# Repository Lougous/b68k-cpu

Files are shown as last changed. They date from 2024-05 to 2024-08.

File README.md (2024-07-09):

# Overview

This is a single board computer based on Motorola 68000. It features:
* 512kiB to 8MiB DRAM (SIMM 30 pins x2)
* basic memory protection / paging
* 8bits expansion bus with 4 slots
* PS/2 keyboard and mouse support
* serial link (TTL)
* boot with serial bootstrap or user flash

Some pictures [here](/doc).

The block diagram below depicts the board architecture:
board architecture

## Board glue logic

Most board glue logic is implemented with an Altera EPM7128S CPLD. This part is obsolete but modern replacement exists with ~~Actel~~ ~~Microsemi~~ Microchip ATF1508AS (never tested though). The CPLD implements:
* DRAM address multiplexing
* DRAM refresh
* basic memory management: base address translation and inbound check with power of two alignment constraints
* 8-bits expansion bus access, for 8-bits wide or 16-bits wide memory cycle from the 68000
* first stage boot procedure, by copying during reset the 512 first bytes from the flash memory (see MFP chip description below) at address 000000h in DRAM. 

Expansion bus also uses a few discrete logic (74245 buffers and 74138 address decoder).

An additional 74148 encodes interrupt sources to CPU IPL0/1/2.

### memory management

The CPLD provides very basic memory management capabilities, for user mode accesses only (FC2 set to 0). It relies on two value set with four registers. These registers are write only, 16-bits, but only the upper bit 15:8 are used.

| register | address | description |
|:---:|:---:|:---|
| MMU_BASE_LO | FE0000h | base address bits 19:12 |
| MMU_BASE_HI | FE0002h | base address bits 22:20 |
| MMU_MASK_LO | FE0004h | address mask bits 19:12 |
| MMU_MASK_HI | FE0006h | address mask bits 21:20 |

Any user address is and'ed with MMU_MASK then or'ed with MMU_BASE. It results in a memory area allocated to a user program with a power of two size, with a base address aligned to its own size. Any user access that targets an address above the allocated size ends with a bus error.

### interrupt management

The autovectored interrupt scheme is used (VPA# assertion). To save pins on the CPLD the FC0 and FC1 are not available to identify an interrupt acknowledge cycle, so any read cycle at FFFFFFh with FC2 set to 1 is considered as such.

### 8-bits expansion bus

This bus provides access to 5 peripherals:
* 4 available through dedicated connectors (2x10 female pin headers)
* 1 embeded to the board: the MFP

It provides for each peripheral up to 128kiB aperture into CPU memory space.

The table below lists the signals on this bus as seen for each slot.

| signal  | type | shared  | description |
|:---:|:---:|:---:|:---:|
| RST# | input | yes | system reset |
| CE# | input | no | access enable |
| ACK# | open drain output | yes | access acknowledge |
| WE# | input | yes | write enable |
| ALE# | input | yes | address latch enable |
| IRQ# | open drain output | option  | interrupt request |
| A0 | input | yes | address bit 0 |
| AD[7:0] | bidir | yes | address / data |

#### single access cycles

This is how translates a byte access from the 68000 (UDS# or LDS# alone)

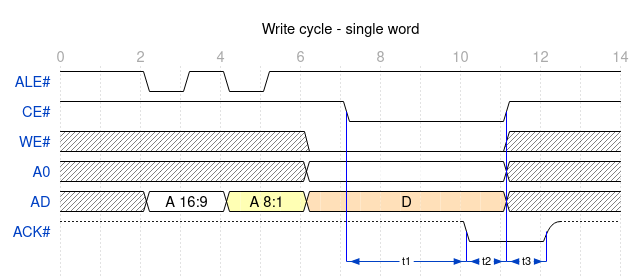
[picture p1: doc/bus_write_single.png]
Write cycle - single word

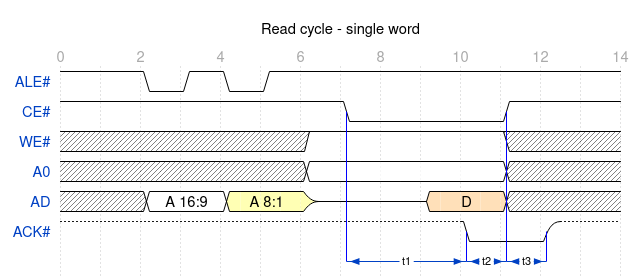
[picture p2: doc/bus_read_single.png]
Read cycle - single word


note: peripherals like the MFP ignore the address bits 16:1 and can ignore the ALE# signal.

#### multiple access cycles

This is how translates a 16-bits access from the 68000 (UDS# and LDS#)

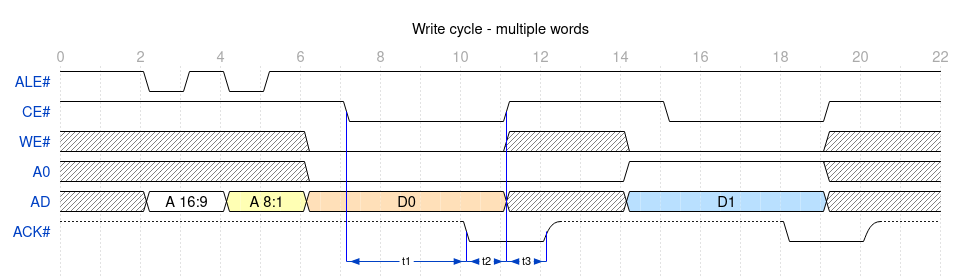
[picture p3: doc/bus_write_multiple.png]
Write cycle - multiple words


### Bootstrap loading

Right after a reset, the CPLD starts by transfering 512 bytes of data from the MFP FLASH_DATA register into the first bytes of DRAM. Then the very first 68000 memory access (at 0000000h) is performed.

Because any software is to be much bigger than just 512-bytes, this chunk of code must itself include assembly instructions to copy the rest of the code - still accessing FLASH_DATA register.

The MFP contains two software images for the 68000:
* a serial bootstrap, loading from the serial interface the binary to jump in, that is enables by pressing 's' key on a keyboard plugged into the PS/2 port
* or an embedded binary to jump in.

To change the embedded binary, the MFP firmware must be recompiled and programmed (the 68000 binary is a constant data table within the microcontroller firmware).

## MFP (multifunction peripheral)

This is a software defined chip base on a PIC18F27K42 microcontroller. It provides:
* embedded flash with 2 software images for the 68000, selection by detecting pressed key at reset. 
* IOs/timer with dedicated low-priority interrupt: two PS/2 port, one serial link, 1 kHz RTC timer
* 250 Hz system timer with dedicated highest-priority interrupt
* hard/soft reset
* debug register (POST or so)

The MFP has only two memory locations accessible through the expansion bus: one to set the actual register to access, the other to read or write data from/to the register.

| register | address | description |
|:---:|:---:|:---|
| MFP_DATA | F00000h | MFP register data |
| MFP_ADDRESS | F00001h | MFP register index |

### Register set

| register | index | description |
|:---:|:---:|:---|
| FLASH_DATA  | 0 | boot flash data access. flash data pointer auto increments |
| TICKS | 3 | 4-us ticks counter, 0-249 |
| UART_STS | 4 | UART status<br>bit 7: TX ready<br>bit 1: RX FIFO overflow<br>bit 0: RX FIFO underflow |
| UART_DATA | 5 | UART data in/out |
| POST | 7 | POST code (debug) |
| PS2P0_STS | 8 | PS/2 port 0 status<br>bit 0: data available |
| PS2P0_DATA  | 9 | PS/2 port 0 data |
| PS2P1_STS | 10 | PS/2 port 1 status<br>bit 0: data available |
| PS2P1_DATA  | 11 | PS/2 port 1 data |
| SYSCFG | 12 | system tick configuration<br>bit 0: enable timer interrupt<br>bit 5: set by bootstap loader to prevent flash to RAM boot transfer<br>bit 6: enable self immediate interrupt<br>bit 7: soft reset |
| SYSSTS | 13 |  system tick status<br>bit 0: timer interrupt pending<br>bit 6: self immediate interrupt pending |
| IRQCFG | 14 | interrupt controller configuration<br>bit 0: enable RTC interrupt<br>bit 1: enable PS/2 keyboard interrupt<br>bit 2: enable PS/2 mouse interrupt<br>bit 3: enable UART RX interrupt |
| IRQSTS | 15 | interrupt controller status<br>bit 0: RTC interrupt pending<br>bit 1: PS/2 keyboard interrupt pending<br>bit 2: PS/2 mouse interrupt pending<br>bit 3: UART RX interrupt pending |

# Memory mapping

| memory range | access | size | memory area
|:---:|:---:|:---:|:-----
| 000000h - 7FFFFFh | U/S | 8MiB | DRAM. memory address translation/mask/check for user mode only |
| 800000h - EFFFFFh | S	 | 7MiB | DO NOT USE. mirrors F00000h - FFFFFFh |
| F00000h - F1FFFFh | S | 128kiB | MFP registers. address bits 16:1 are ignored |
| F20000h - F3FFFFh | S | 128kiB | expansion bus connector J9 |
| F40000h - F5FFFFh | S | 128kiB | expansion bus connector J11 |
| F60000h - F7FFFFh | S | 128kiB | DO NOT USE. reserved for expansion bus hardware implementation |
| F80000h - F9FFFFh | U*/S | 128kiB | expansion bus connector J10. *: user access to be removed |
| FA0000h - FBFFFFh | S | 128kiB | DO NOT USE. unmapped, might be used for another peripheral slot |
| FC0000h - FDFFFFh | S | 128kiB | expansion bus connector J8 |
| FE0000h - FFFFFFh | S | 128kiB | restricted to PMMU register configuration |

# BOM

This table below is no spec, it just shows the parts that equip the board on my desk.

| Reference  | Part |
|:---:|:---:|
| RN1 | not populated |
| U1 | MC68HC000FN20 |
| U2 | 74F138 |
| U3, U6, U7 | 74F245 |
| U4 | EPM7128SLC84-10 |
| U5 | PIC18F27K42SP |
| U8 | 74HC148 |
| X2 | 12-MHz |

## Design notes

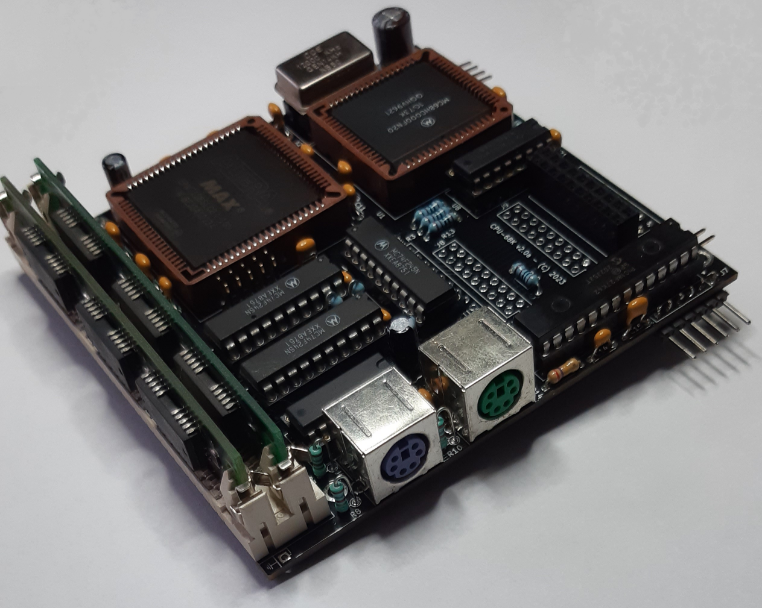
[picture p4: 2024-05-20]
doc/b68k-cpu.png

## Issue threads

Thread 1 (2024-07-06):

boot sector corruption at startup

Lougous, 2024-07-06:
The very first byte copied from MFP to DRAM by the boot DMA is sometimes corrupted.
First byte copied is at address 000001h => part of reset stack address, that is not used (set by dedicated instruction in reset handler)

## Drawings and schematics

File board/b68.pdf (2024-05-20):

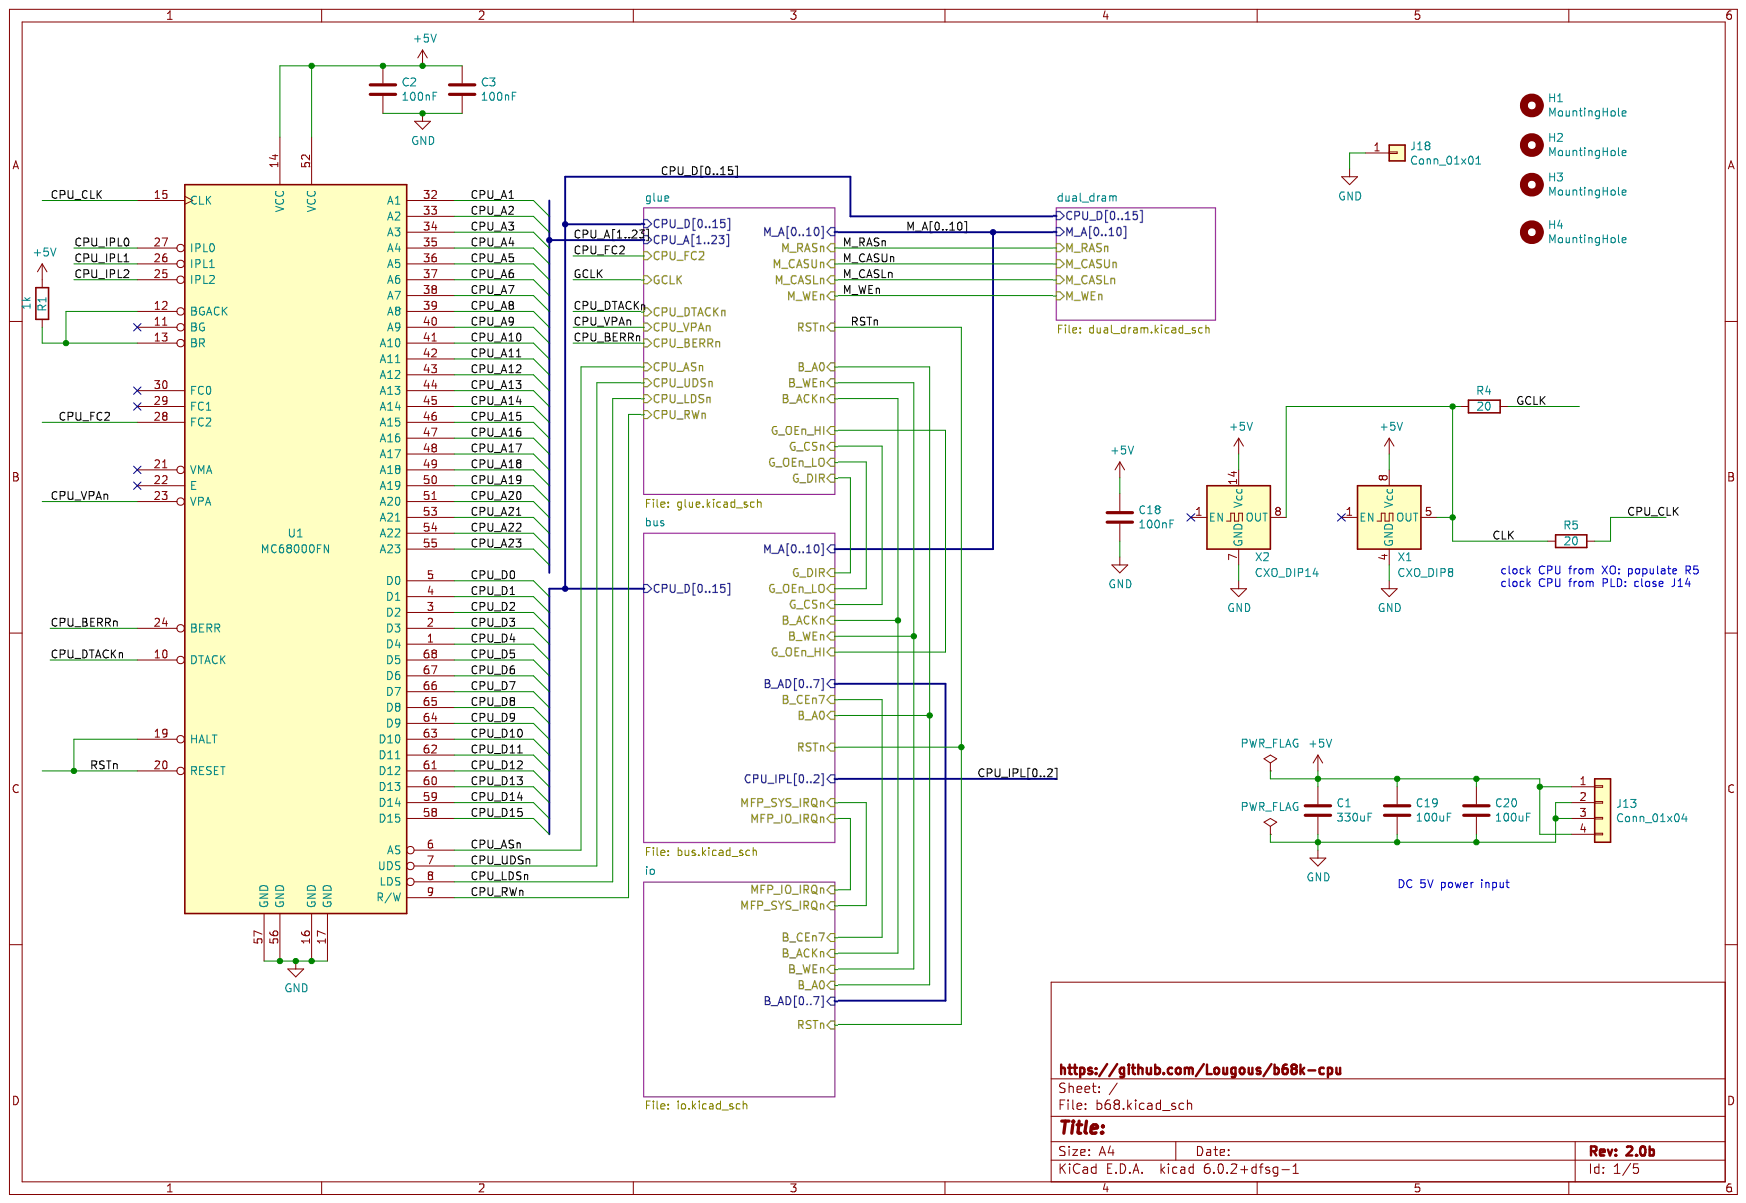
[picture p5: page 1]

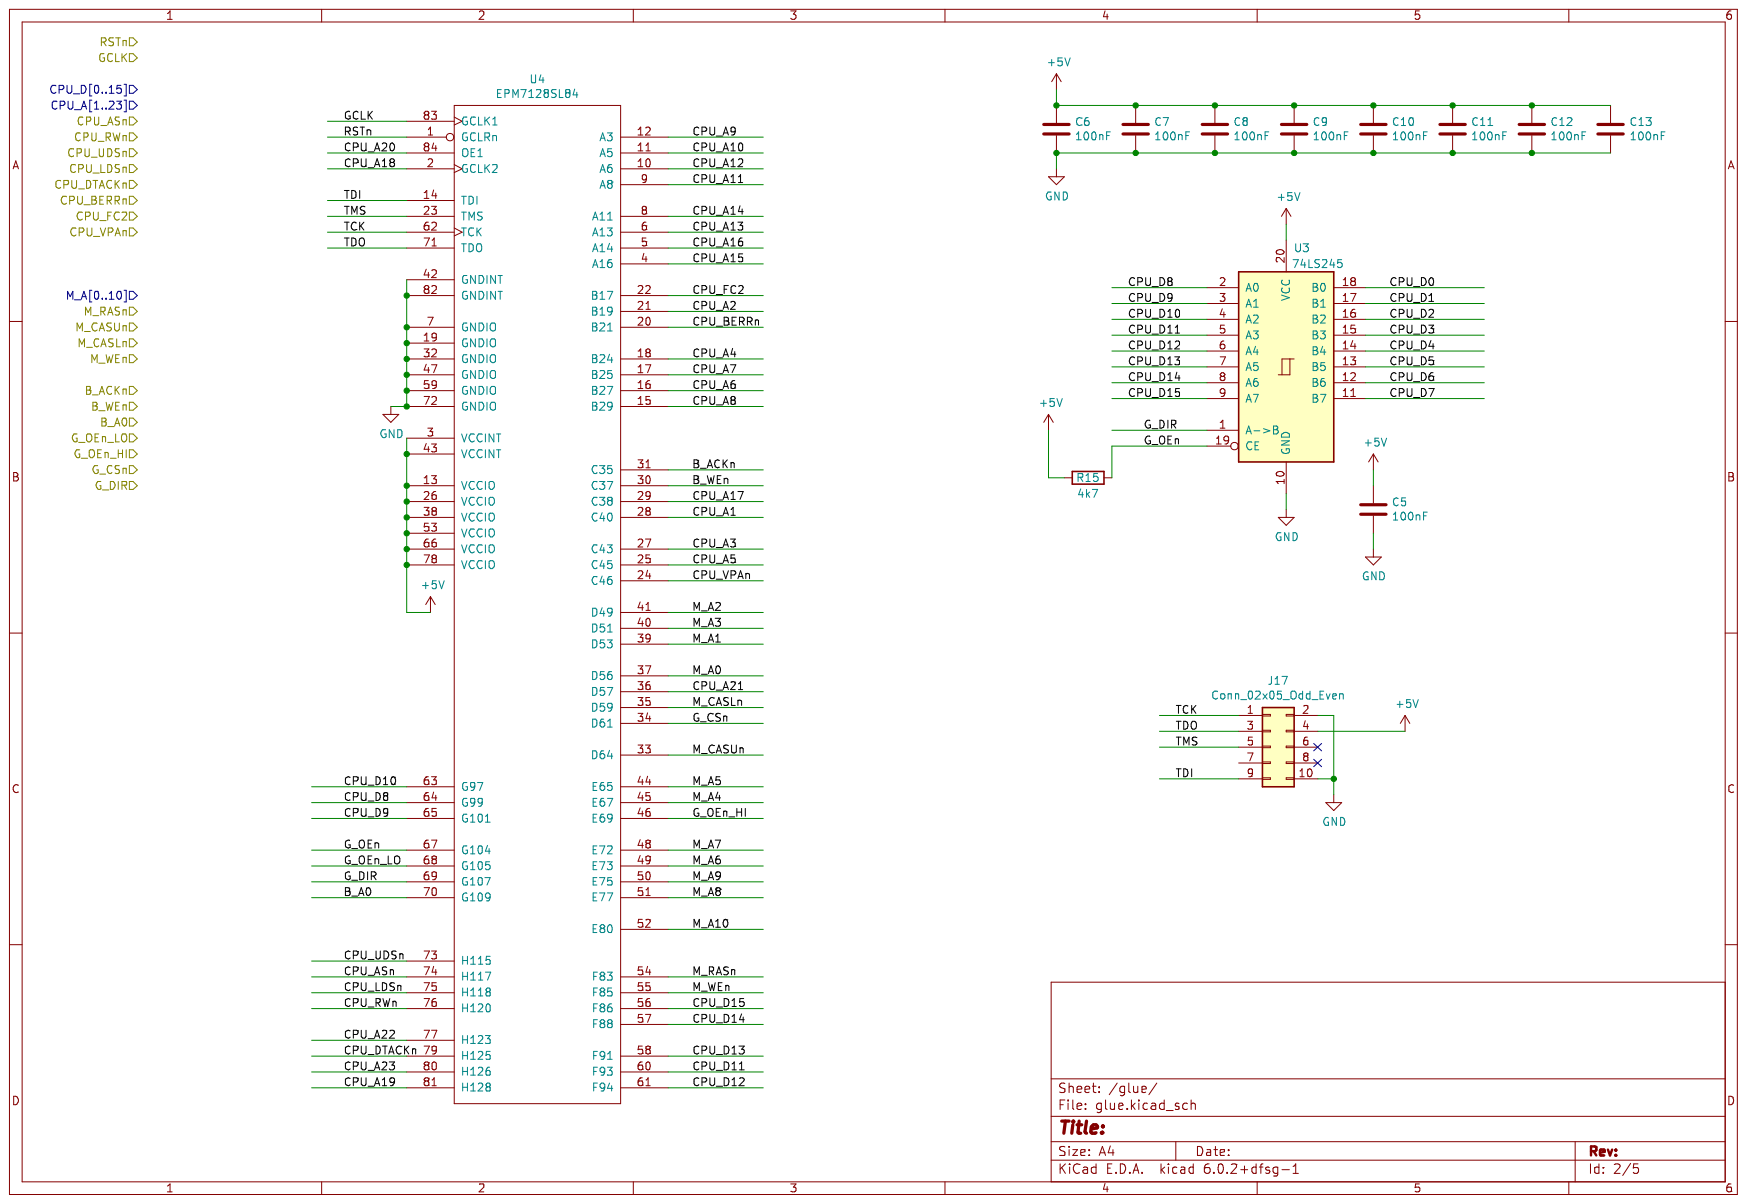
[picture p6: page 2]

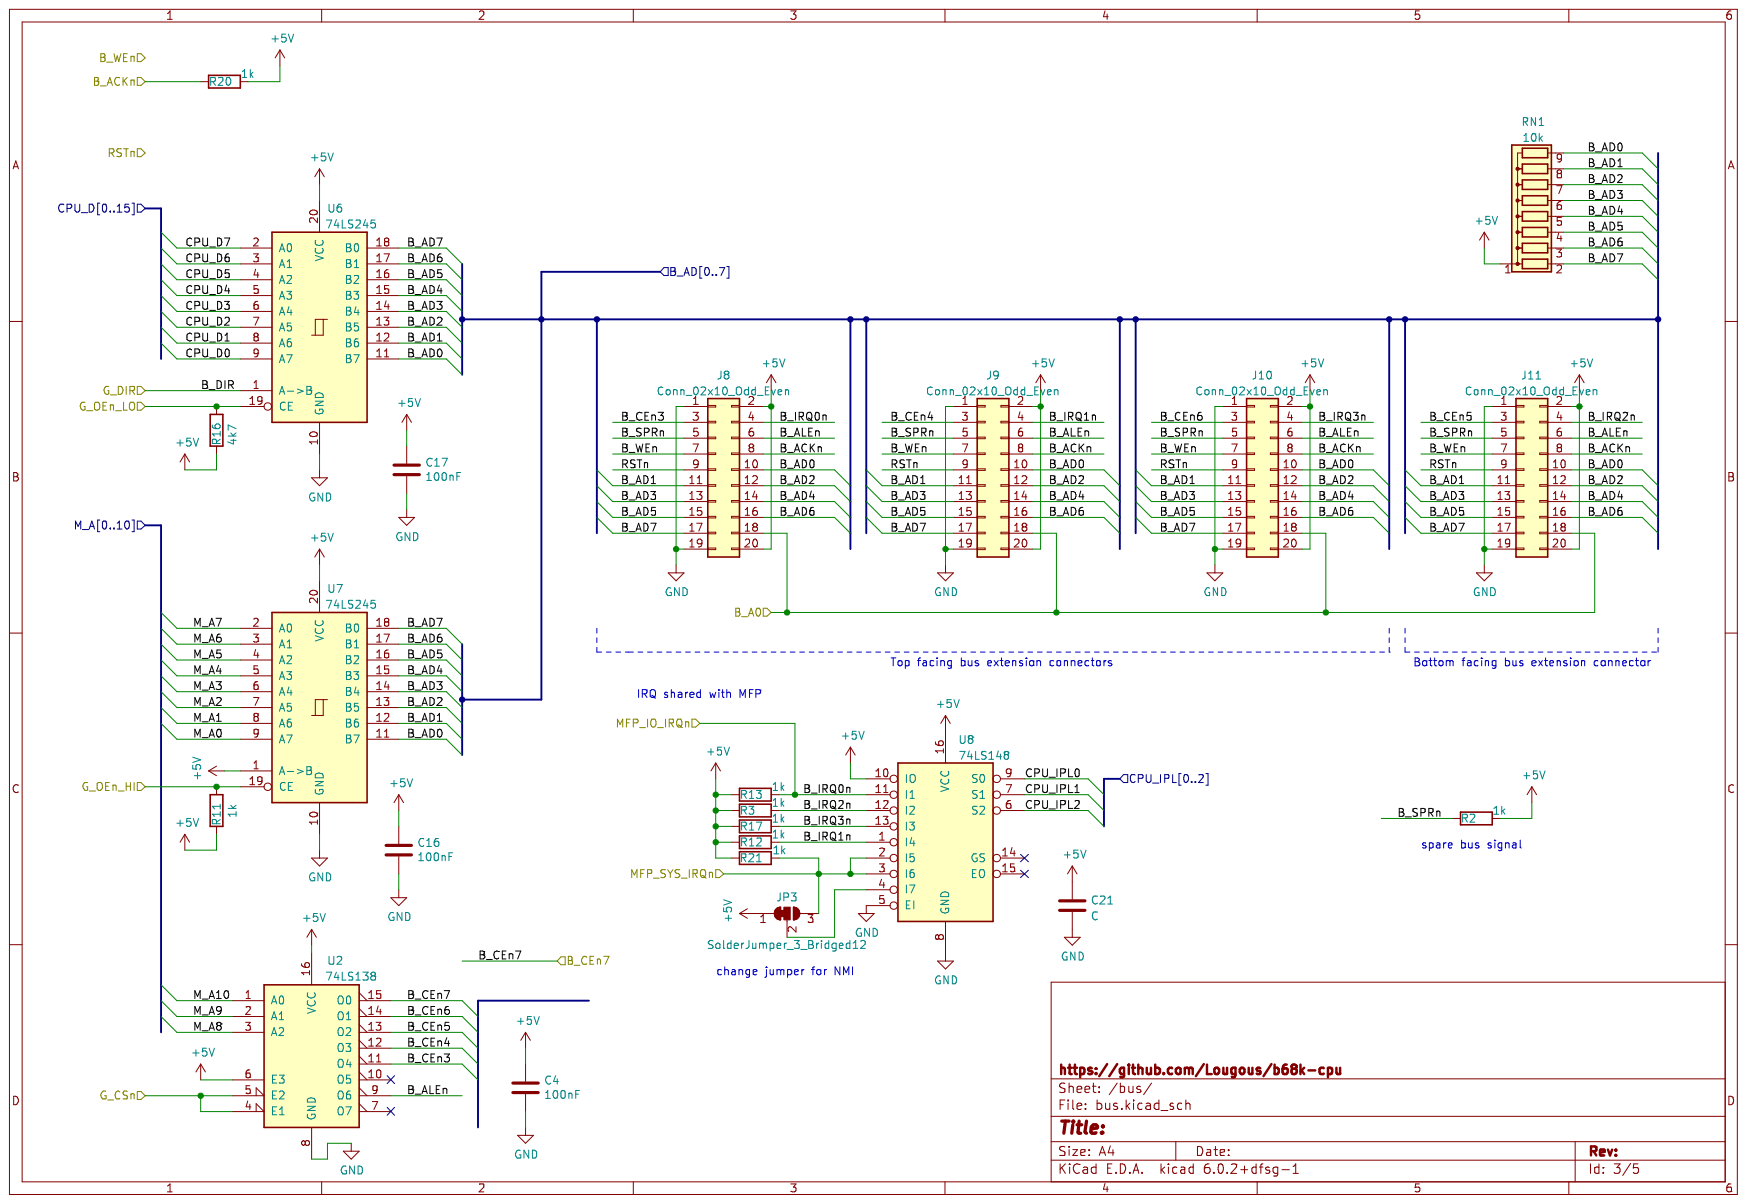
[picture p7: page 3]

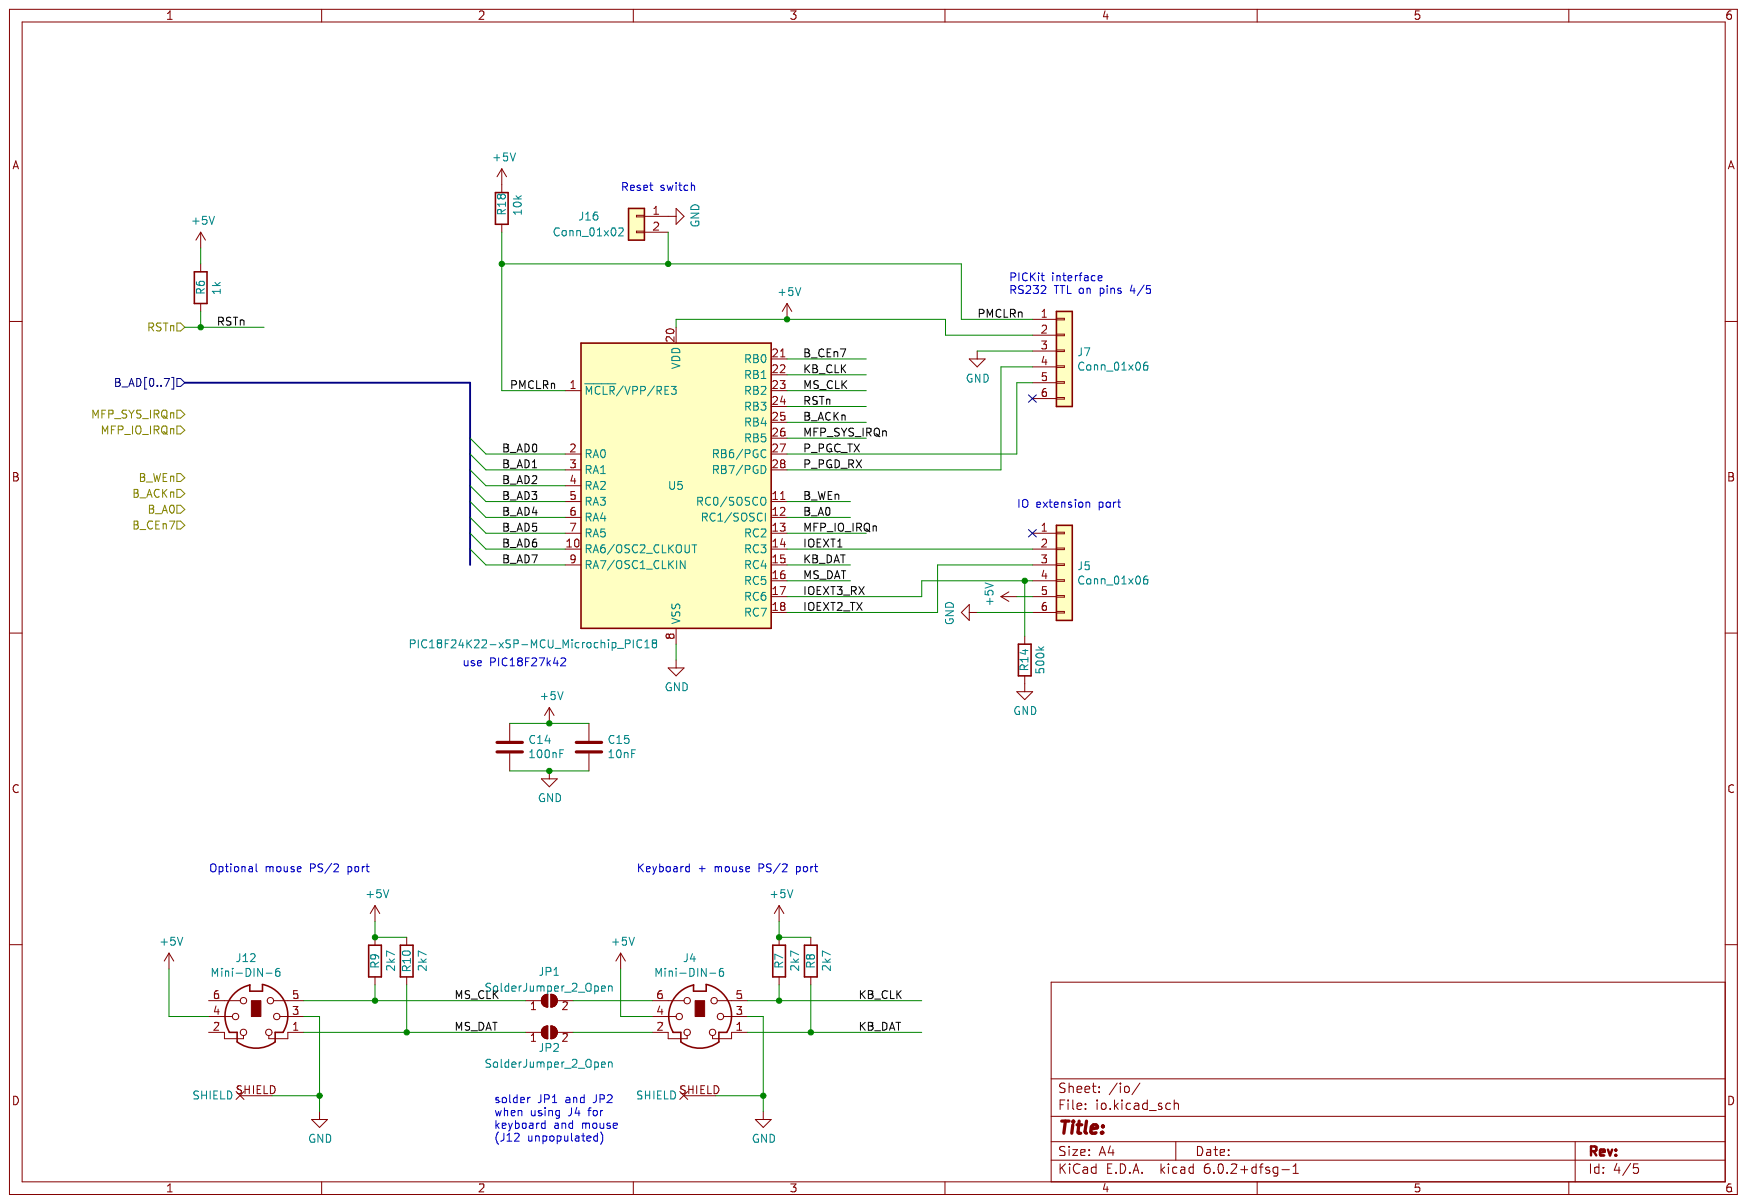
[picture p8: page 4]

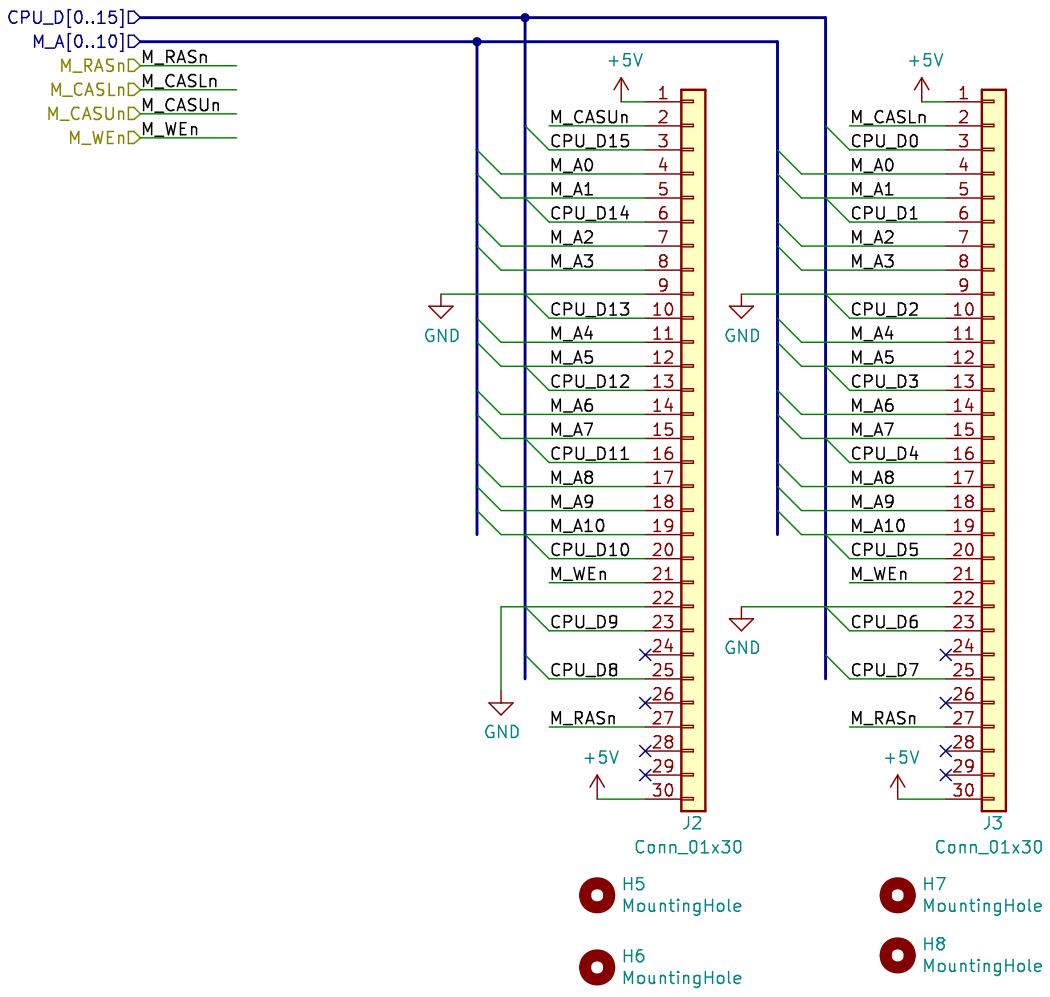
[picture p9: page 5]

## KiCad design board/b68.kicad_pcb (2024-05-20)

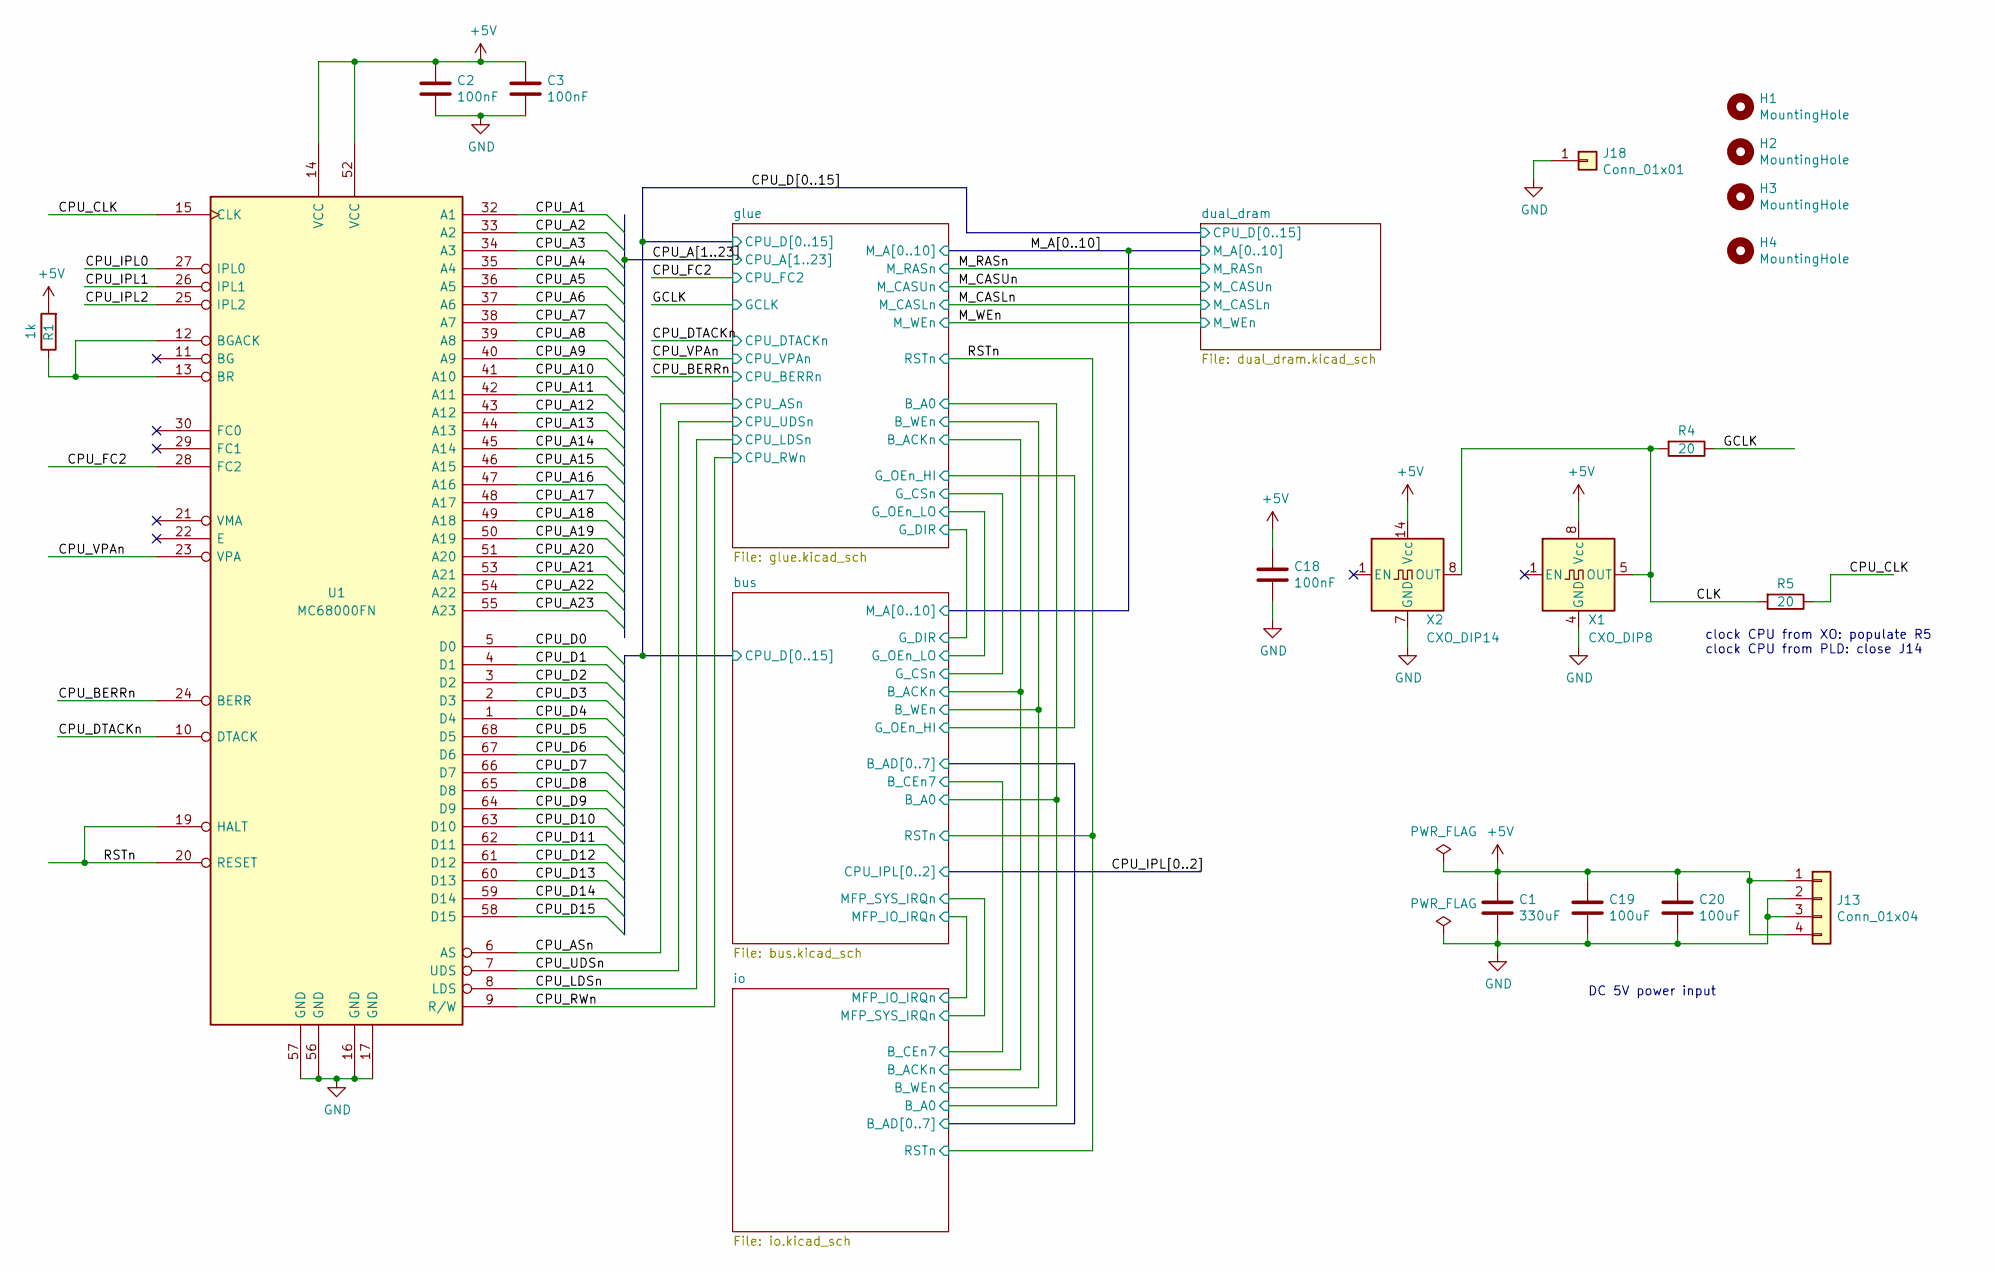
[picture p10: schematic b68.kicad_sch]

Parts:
C1: 330uF; CP_Radial_D8.0mm_P3.50mm
C2, C3, C18: 100nF; C_Disc_D4.3mm_W1.9mm_P5.00mm
C19, C20: 100uF; CP_Radial_D5.0mm_P2.50mm
H1, H2, H3, H4: MountingHole; MountingHole_2.7mm_M2.5_DIN965_Pad
J13: Conn_01x04; PinHeader_1x04_P2.54mm_Vertical
J18: Conn_01x01; PinHeader_1x01_P2.54mm_Vertical
R1: 1k; R_Axial_DIN0204_L3.6mm_D1.6mm_P7.62mm_Horizontal
R4, R5: 20; R_Axial_DIN0204_L3.6mm_D1.6mm_P7.62mm_Horizontal
U1: MC68000FN; PLCC-68_THT-Socket
X1: CXO_DIP8; Oscillator_DIP-8
X2: CXO_DIP14; Oscillator_DIP-14

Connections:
+5V: C1.1, C2.1, C3.1, C18.1, C19.1, C20.1, J13.1, J13.4, R1.2, U1.14 (VCC), U1.52 (VCC), X1.8 (Vcc), X2.14 (Vcc); also elsewhere on the board
/CLK: R4.2, R5.2, X1.5 (OUT), X2.8 (OUT)
/CPU_A1: U1.32 (A1); also elsewhere on the board
/CPU_A2: U1.33 (A2); also elsewhere on the board
/CPU_A3: U1.34 (A3); also elsewhere on the board
/CPU_A4: U1.35 (A4); also elsewhere on the board
/CPU_A5: U1.36 (A5); also elsewhere on the board
/CPU_A6: U1.37 (A6); also elsewhere on the board
/CPU_A7: U1.38 (A7); also elsewhere on the board
/CPU_A8: U1.39 (A8); also elsewhere on the board
/CPU_A9: U1.40 (A9); also elsewhere on the board
/CPU_A10: U1.41 (A10); also elsewhere on the board
/CPU_A11: U1.42 (A11); also elsewhere on the board
/CPU_A12: U1.43 (A12); also elsewhere on the board
/CPU_A13: U1.44 (A13); also elsewhere on the board
/CPU_A14: U1.45 (A14); also elsewhere on the board
/CPU_A15: U1.46 (A15); also elsewhere on the board
/CPU_A16: U1.47 (A16); also elsewhere on the board
/CPU_A17: U1.48 (A17); also elsewhere on the board
/CPU_A18: U1.49 (A18); also elsewhere on the board
/CPU_A19: U1.50 (A19); also elsewhere on the board
/CPU_A20: U1.51 (A20); also elsewhere on the board
/CPU_A21: U1.53 (A21); also elsewhere on the board
/CPU_A22: U1.54 (A22); also elsewhere on the board
/CPU_A23: U1.55 (A23); also elsewhere on the board
/CPU_ASn: U1.6 (AS); also elsewhere on the board
/CPU_BERRn: U1.24 (BERR); also elsewhere on the board
/CPU_CLK: R5.1, U1.15 (CLK)
/CPU_D0: U1.5 (D0); also elsewhere on the board
/CPU_D1: U1.4 (D1); also elsewhere on the board
/CPU_D2: U1.3 (D2); also elsewhere on the board
/CPU_D3: U1.2 (D3); also elsewhere on the board
/CPU_D4: U1.1 (D4); also elsewhere on the board
/CPU_D5: U1.68 (D5); also elsewhere on the board
/CPU_D6: U1.67 (D6); also elsewhere on the board
/CPU_D7: U1.66 (D7); also elsewhere on the board
/CPU_D8: U1.65 (D8); also elsewhere on the board
/CPU_D9: U1.64 (D9); also elsewhere on the board
/CPU_D10: U1.63 (D10); also elsewhere on the board
/CPU_D11: U1.62 (D11); also elsewhere on the board
/CPU_D12: U1.61 (D12); also elsewhere on the board
/CPU_D13: U1.60 (D13); also elsewhere on the board
/CPU_D14: U1.59 (D14); also elsewhere on the board
/CPU_D15: U1.58 (D15); also elsewhere on the board
/CPU_DTACKn: U1.10 (DTACK); also elsewhere on the board
/CPU_FC2: U1.28 (FC2); also elsewhere on the board
/CPU_IPL0: U1.27 (IPL0); also elsewhere on the board
/CPU_IPL1: U1.26 (IPL1); also elsewhere on the board
/CPU_IPL2: U1.25 (IPL2); also elsewhere on the board
/CPU_LDSn: U1.8 (LDS); also elsewhere on the board
/CPU_RWn: U1.9 (R/W); also elsewhere on the board
/CPU_UDSn: U1.7 (UDS); also elsewhere on the board
/CPU_VPAn: U1.23 (VPA); also elsewhere on the board
/GCLK: R4.1; also elsewhere on the board
/RSTn: U1.19 (HALT), U1.20 (RESET); also elsewhere on the board
GND: C1.2, C2.2, C3.2, C18.2, C19.2, C20.2, J13.2, J13.3, J18.1, U1.16 (GND), U1.17 (GND), U1.56 (GND), U1.57 (GND), X1.4 (GND), X2.7 (GND); also elsewhere on the board
unnamed: R1.1, U1.12 (BGACK), U1.13 (BR)

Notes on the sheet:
clock CPU from XO: populate R5 clock CPU from PLD: close J14
DC 5V power input

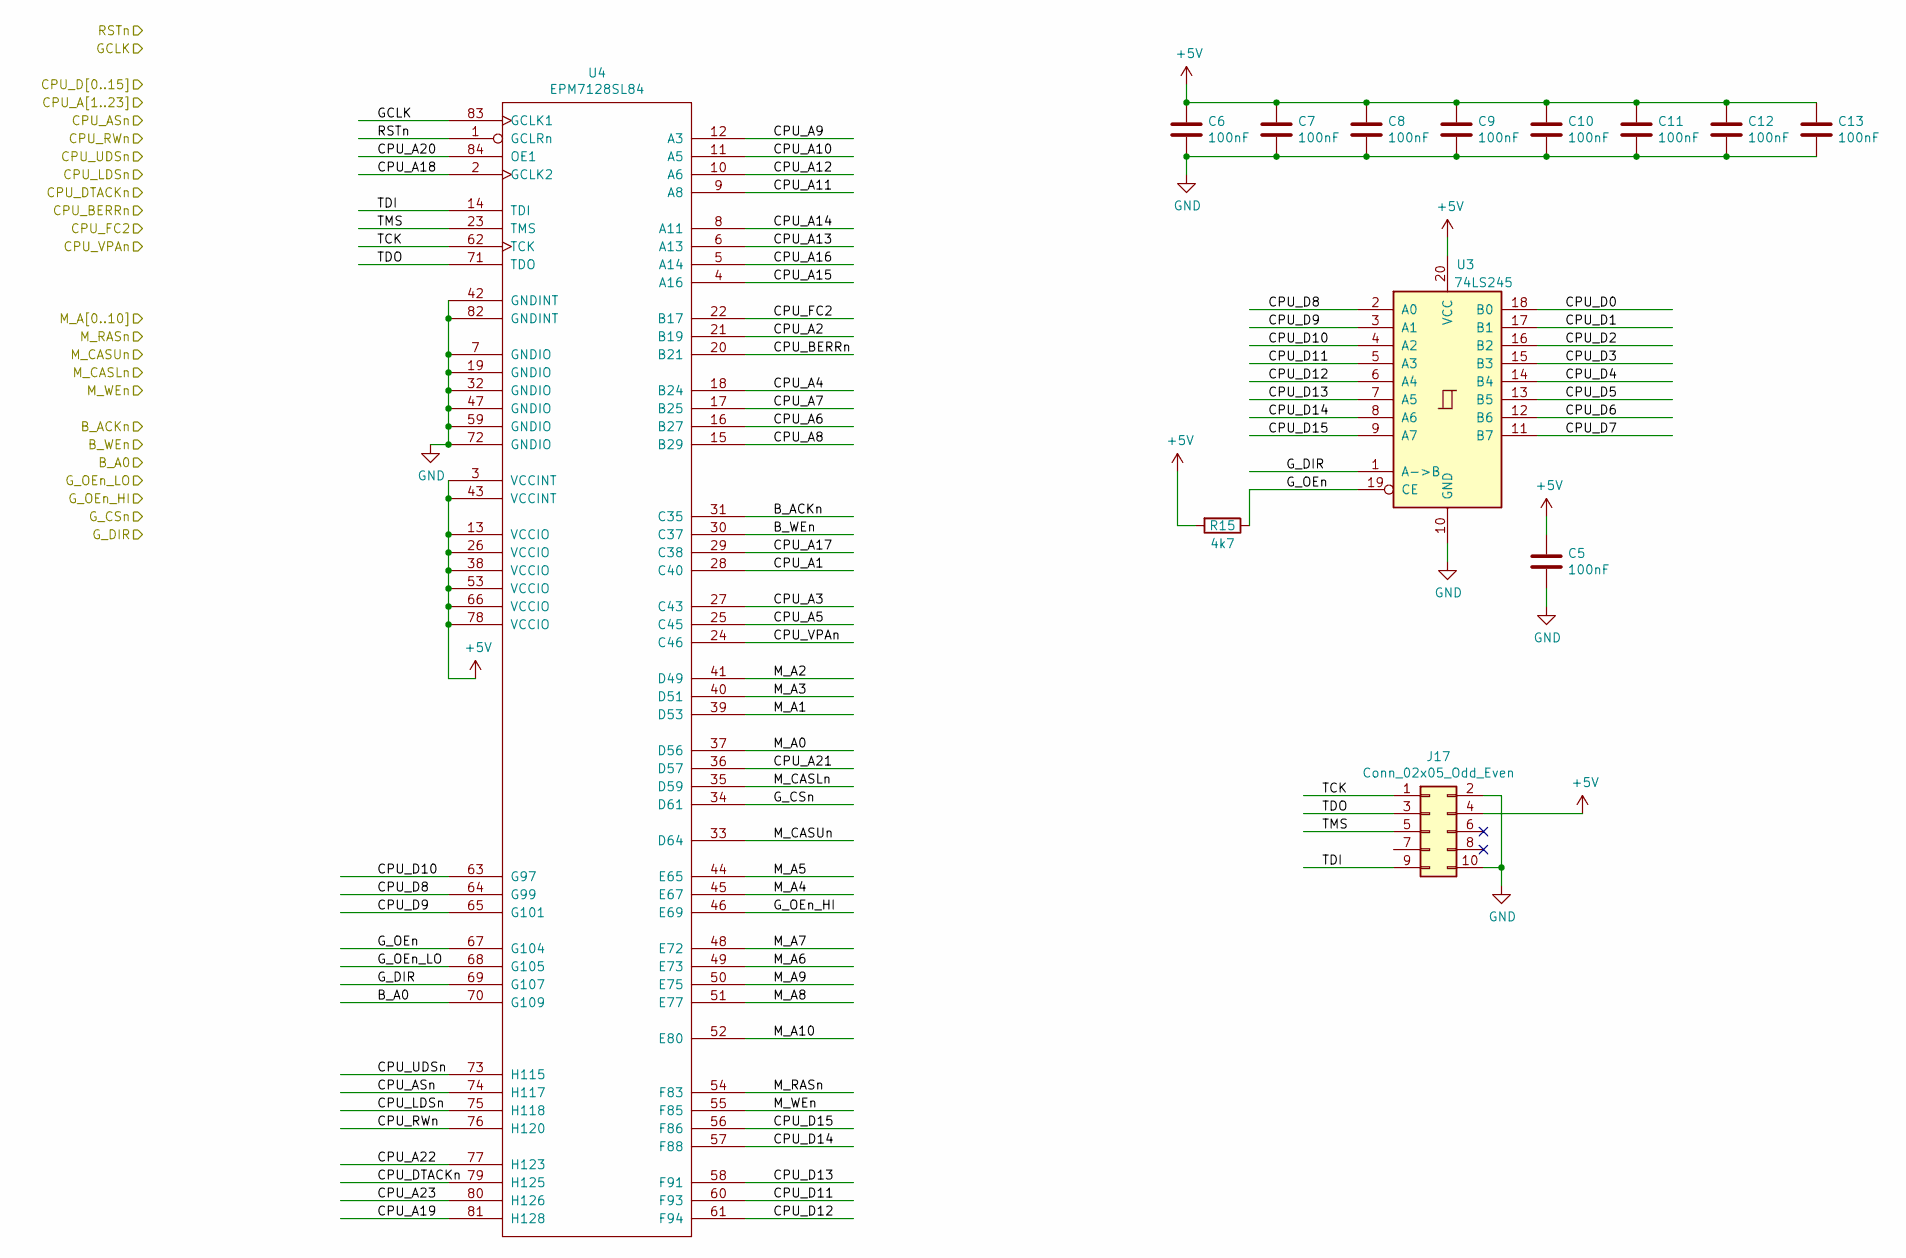
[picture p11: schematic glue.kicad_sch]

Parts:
C5, C6, C7, C8, C9, C10, C11, C12, C13: 100nF; C_Disc_D4.3mm_W1.9mm_P5.00mm
J17: Conn_02x05_Odd_Even; PinHeader_2x05_P2.54mm_Vertical
R15: 4k7; R_Axial_DIN0204_L3.6mm_D1.6mm_P2.54mm_Vertical
U3: 74LS245; DIP-20_W7.62mm_Socket
U4: EPM7128SL84; PLCC-84_THT-Socket

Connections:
+5V: C5.1, C6.1, C7.1, C8.1, C9.1, C10.1, C11.1, C12.1, C13.1, J17.4, R15.2, U3.20 (VCC), U4.3 (VCCINT), U4.13 (VCCIO), U4.26 (VCCIO), U4.38 (VCCIO), U4.43 (VCCINT), U4.53 (VCCIO), U4.66 (VCCIO), U4.78 (VCCIO); also elsewhere on the board
/CPU_A1: U4.28 (C40); also elsewhere on the board
/CPU_A2: U4.21 (B19); also elsewhere on the board
/CPU_A3: U4.27 (C43); also elsewhere on the board
/CPU_A4: U4.18 (B24); also elsewhere on the board
/CPU_A5: U4.25 (C45); also elsewhere on the board
/CPU_A6: U4.16 (B27); also elsewhere on the board
/CPU_A7: U4.17 (B25); also elsewhere on the board
/CPU_A8: U4.15 (B29); also elsewhere on the board
/CPU_A9: U4.12 (A3); also elsewhere on the board
/CPU_A10: U4.11 (A5); also elsewhere on the board
/CPU_A11: U4.9 (A8); also elsewhere on the board
/CPU_A12: U4.10 (A6); also elsewhere on the board
/CPU_A13: U4.6 (A13); also elsewhere on the board
/CPU_A14: U4.8 (A11); also elsewhere on the board
/CPU_A15: U4.4 (A16); also elsewhere on the board
/CPU_A16: U4.5 (A14); also elsewhere on the board
/CPU_A17: U4.29 (C38); also elsewhere on the board
/CPU_A18: U4.2 (GCLK2); also elsewhere on the board
/CPU_A19: U4.81 (H128); also elsewhere on the board
/CPU_A20: U4.84 (OE1); also elsewhere on the board
/CPU_A21: U4.36 (D57); also elsewhere on the board
/CPU_A22: U4.77 (H123); also elsewhere on the board
/CPU_A23: U4.80 (H126); also elsewhere on the board
/CPU_ASn: U4.74 (H117); also elsewhere on the board
/CPU_BERRn: U4.20 (B21); also elsewhere on the board
/CPU_D0: U3.18 (B0); also elsewhere on the board
/CPU_D1: U3.17 (B1); also elsewhere on the board
/CPU_D2: U3.16 (B2); also elsewhere on the board
/CPU_D3: U3.15 (B3); also elsewhere on the board
/CPU_D4: U3.14 (B4); also elsewhere on the board
/CPU_D5: U3.13 (B5); also elsewhere on the board
/CPU_D6: U3.12 (B6); also elsewhere on the board
/CPU_D7: U3.11 (B7); also elsewhere on the board
/CPU_D8: U3.2 (A0), U4.64 (G99); also elsewhere on the board
/CPU_D9: U3.3 (A1), U4.65 (G101); also elsewhere on the board
/CPU_D10: U3.4 (A2), U4.63 (G97); also elsewhere on the board
/CPU_D11: U3.5 (A3), U4.60 (F93); also elsewhere on the board
/CPU_D12: U3.6 (A4), U4.61 (F94); also elsewhere on the board
/CPU_D13: U3.7 (A5), U4.58 (F91); also elsewhere on the board
/CPU_D14: U3.8 (A6), U4.57 (F88); also elsewhere on the board
/CPU_D15: U3.9 (A7), U4.56 (F86); also elsewhere on the board
/CPU_DTACKn: U4.79 (H125); also elsewhere on the board
/CPU_FC2: U4.22 (B17); also elsewhere on the board
/CPU_LDSn: U4.75 (H118); also elsewhere on the board
/CPU_RWn: U4.76 (H120); also elsewhere on the board
/CPU_UDSn: U4.73 (H115); also elsewhere on the board
/CPU_VPAn: U4.24 (C46); also elsewhere on the board
/GCLK: U4.83 (GCLK1); also elsewhere on the board
/M_A0: U4.37 (D56); also elsewhere on the board
/M_A1: U4.39 (D53); also elsewhere on the board
/M_A2: U4.41 (D49); also elsewhere on the board
/M_A3: U4.40 (D51); also elsewhere on the board
/M_A4: U4.45 (E67); also elsewhere on the board
/M_A5: U4.44 (E65); also elsewhere on the board
/M_A6: U4.49 (E73); also elsewhere on the board
/M_A7: U4.48 (E72); also elsewhere on the board
/M_A8: U4.51 (E77); also elsewhere on the board
/M_A9: U4.50 (E75); also elsewhere on the board
/M_A10: U4.52 (E80); also elsewhere on the board
/M_CASLn: U4.35 (D59); also elsewhere on the board
/M_CASUn: U4.33 (D64); also elsewhere on the board
/M_RASn: U4.54 (F83); also elsewhere on the board
/M_WEn: U4.55 (F85); also elsewhere on the board
/RSTn: U4.1 (GCLRn); also elsewhere on the board
/bus/B_ACKn: U4.31 (C35); also elsewhere on the board
/bus/B_DIR: U3.1 (A->B), U4.69 (G107); also elsewhere on the board
/bus/B_WEn: U4.30 (C37); also elsewhere on the board
/glue/B_A0: U4.70 (G109); also elsewhere on the board
/glue/G_CSn: U4.34 (D61); also elsewhere on the board
/glue/G_OEn: R15.1, U3.19 (CE), U4.67 (G104)
/glue/G_OEn_HI: U4.46 (E69); also elsewhere on the board
/glue/G_OEn_LO: U4.68 (G105); also elsewhere on the board
/glue/TCK: J17.1, U4.62 (TCK)
/glue/TDI: J17.9, U4.14 (TDI)
/glue/TDO: J17.3, U4.71 (TDO)
/glue/TMS: J17.5, U4.23 (TMS)
GND: C5.2, C6.2, C7.2, C8.2, C9.2, C10.2, C11.2, C12.2, C13.2, J17.2, J17.10, U3.10 (GND), U4.7 (GNDIO), U4.19 (GNDIO), U4.32 (GNDIO), U4.42 (GNDINT), U4.47 (GNDIO), U4.59 (GNDIO), U4.72 (GNDIO), U4.82 (GNDINT); also elsewhere on the board

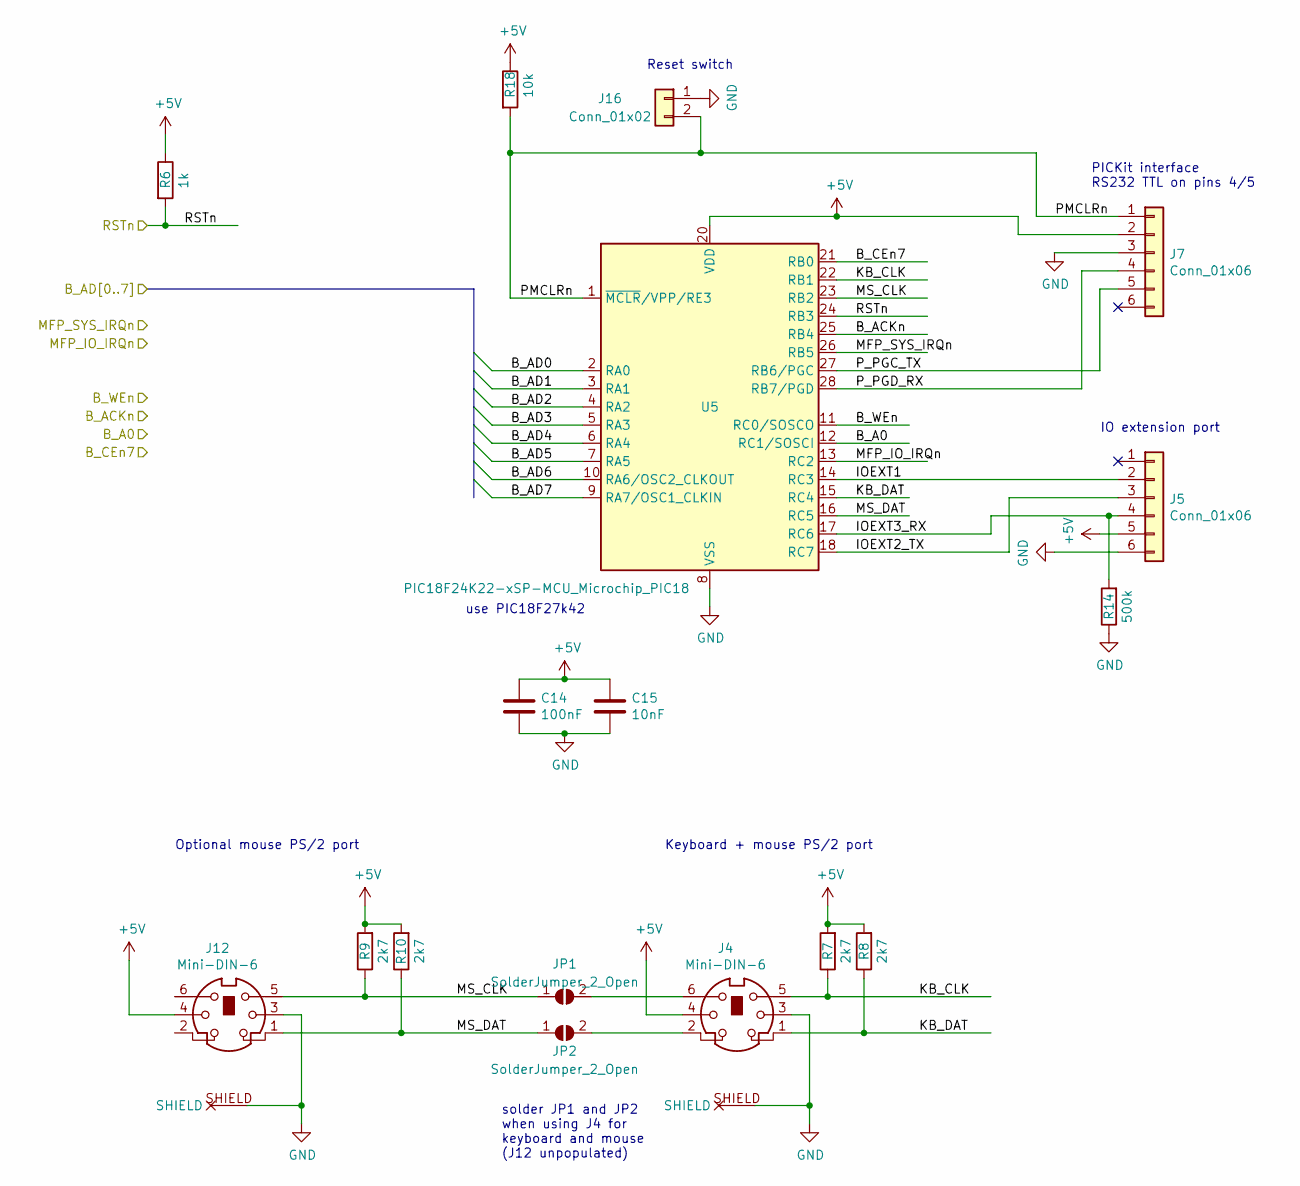
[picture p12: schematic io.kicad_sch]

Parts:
C14: 100nF; C_Disc_D4.3mm_W1.9mm_P5.00mm
C15: 10nF; C_Disc_D4.3mm_W1.9mm_P5.00mm
J4, J12: Mini-DIN-6; mini-DIN_6_PS2
J5, J7: Conn_01x06; PinHeader_1x06_P2.54mm_Vertical
J16: Conn_01x02; PinHeader_1x02_P2.54mm_Vertical
JP1, JP2: SolderJumper_2_Open; SolderJumper-2_P1.3mm_Open_RoundedPad1.0x1.5mm
R6: 1k; R_Axial_DIN0204_L3.6mm_D1.6mm_P7.62mm_Horizontal
R7, R8, R9, R10: 2k7; R_Axial_DIN0204_L3.6mm_D1.6mm_P2.54mm_Vertical
R14: 500k; R_Axial_DIN0204_L3.6mm_D1.6mm_P7.62mm_Horizontal
R18: 10k; R_Axial_DIN0204_L3.6mm_D1.6mm_P7.62mm_Horizontal
U5: PIC18F24K22-xSP-MCU_Microchip_PIC18; DIP-28_W7.62mm_Socket

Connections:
+5V: C14.1, C15.1, J4.4, J5.5, J7.2, J12.4, R6.1, R7.2, R8.2, R9.2, R10.2, R18.1, U5.20 (VDD); also elsewhere on the board
/RSTn: R6.2, U5.24 (RB3); also elsewhere on the board
/bus/B_ACKn: U5.25 (RB4); also elsewhere on the board
/bus/B_AD0: U5.2 (RA0); also elsewhere on the board
/bus/B_AD1: U5.3 (RA1); also elsewhere on the board
/bus/B_AD2: U5.4 (RA2); also elsewhere on the board
/bus/B_AD3: U5.5 (RA3); also elsewhere on the board
/bus/B_AD4: U5.6 (RA4); also elsewhere on the board
/bus/B_AD5: U5.7 (RA5); also elsewhere on the board
/bus/B_AD6: U5.10 (RA6/OSC2_CLKOUT); also elsewhere on the board
/bus/B_AD7: U5.9 (RA7/OSC1_CLKIN); also elsewhere on the board
/bus/B_CEn7: U5.21 (RB0); also elsewhere on the board
/bus/B_IRQ0n: U5.13 (RC2); also elsewhere on the board
/bus/B_WEn: U5.11 (RC0/SOSCO); also elsewhere on the board
/glue/B_A0: U5.12 (RC1/SOSCI); also elsewhere on the board
/io/IOEXT1: J5.2, U5.14 (RC3)
/io/IOEXT2_TX: J5.3, U5.18 (RC7)
/io/IOEXT3_RX: J5.4, R14.2, U5.17 (RC6)
/io/KB_CLK: J4.5, R7.1, U5.22 (RB1)
/io/KB_DAT: J4.1, R8.1, U5.15 (RC4)
/io/MFP_SYS_IRQn: U5.26 (RB5); also elsewhere on the board
/io/MS_CLK: J12.5, JP1.1 (A), R9.1, U5.23 (RB2)
/io/MS_DAT: J12.1, JP2.1 (A), R10.1, U5.16 (RC5)
/io/PMCLRn: J7.1, J16.2, R18.2, U5.1 (~MCLR/VPP/RE3)
/io/P_PGC_TX: J7.5, U5.27 (RB6/PGC)
/io/P_PGD_RX: J7.4, U5.28 (RB7/PGD)
GND: C14.2, C15.2, J4.3, J4.SHIELD, J5.6, J7.3, J12.3, J12.SHIELD, J16.1, R14.1, U5.8 (VSS), U5.19 (VSS); also elsewhere on the board
unnamed: J4.2, JP2.2 (B)
unnamed: J4.6, JP1.2 (B)

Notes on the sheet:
use PIC18F27k42
Optional mouse PS/2 port
IO extension port
Reset switch
solder JP1 and JP2 when using J4 for keyboard and mouse (J12 unpopulated)
PICKit interface RS232 TTL on pins 4/5
Keyboard + mouse PS/2 port

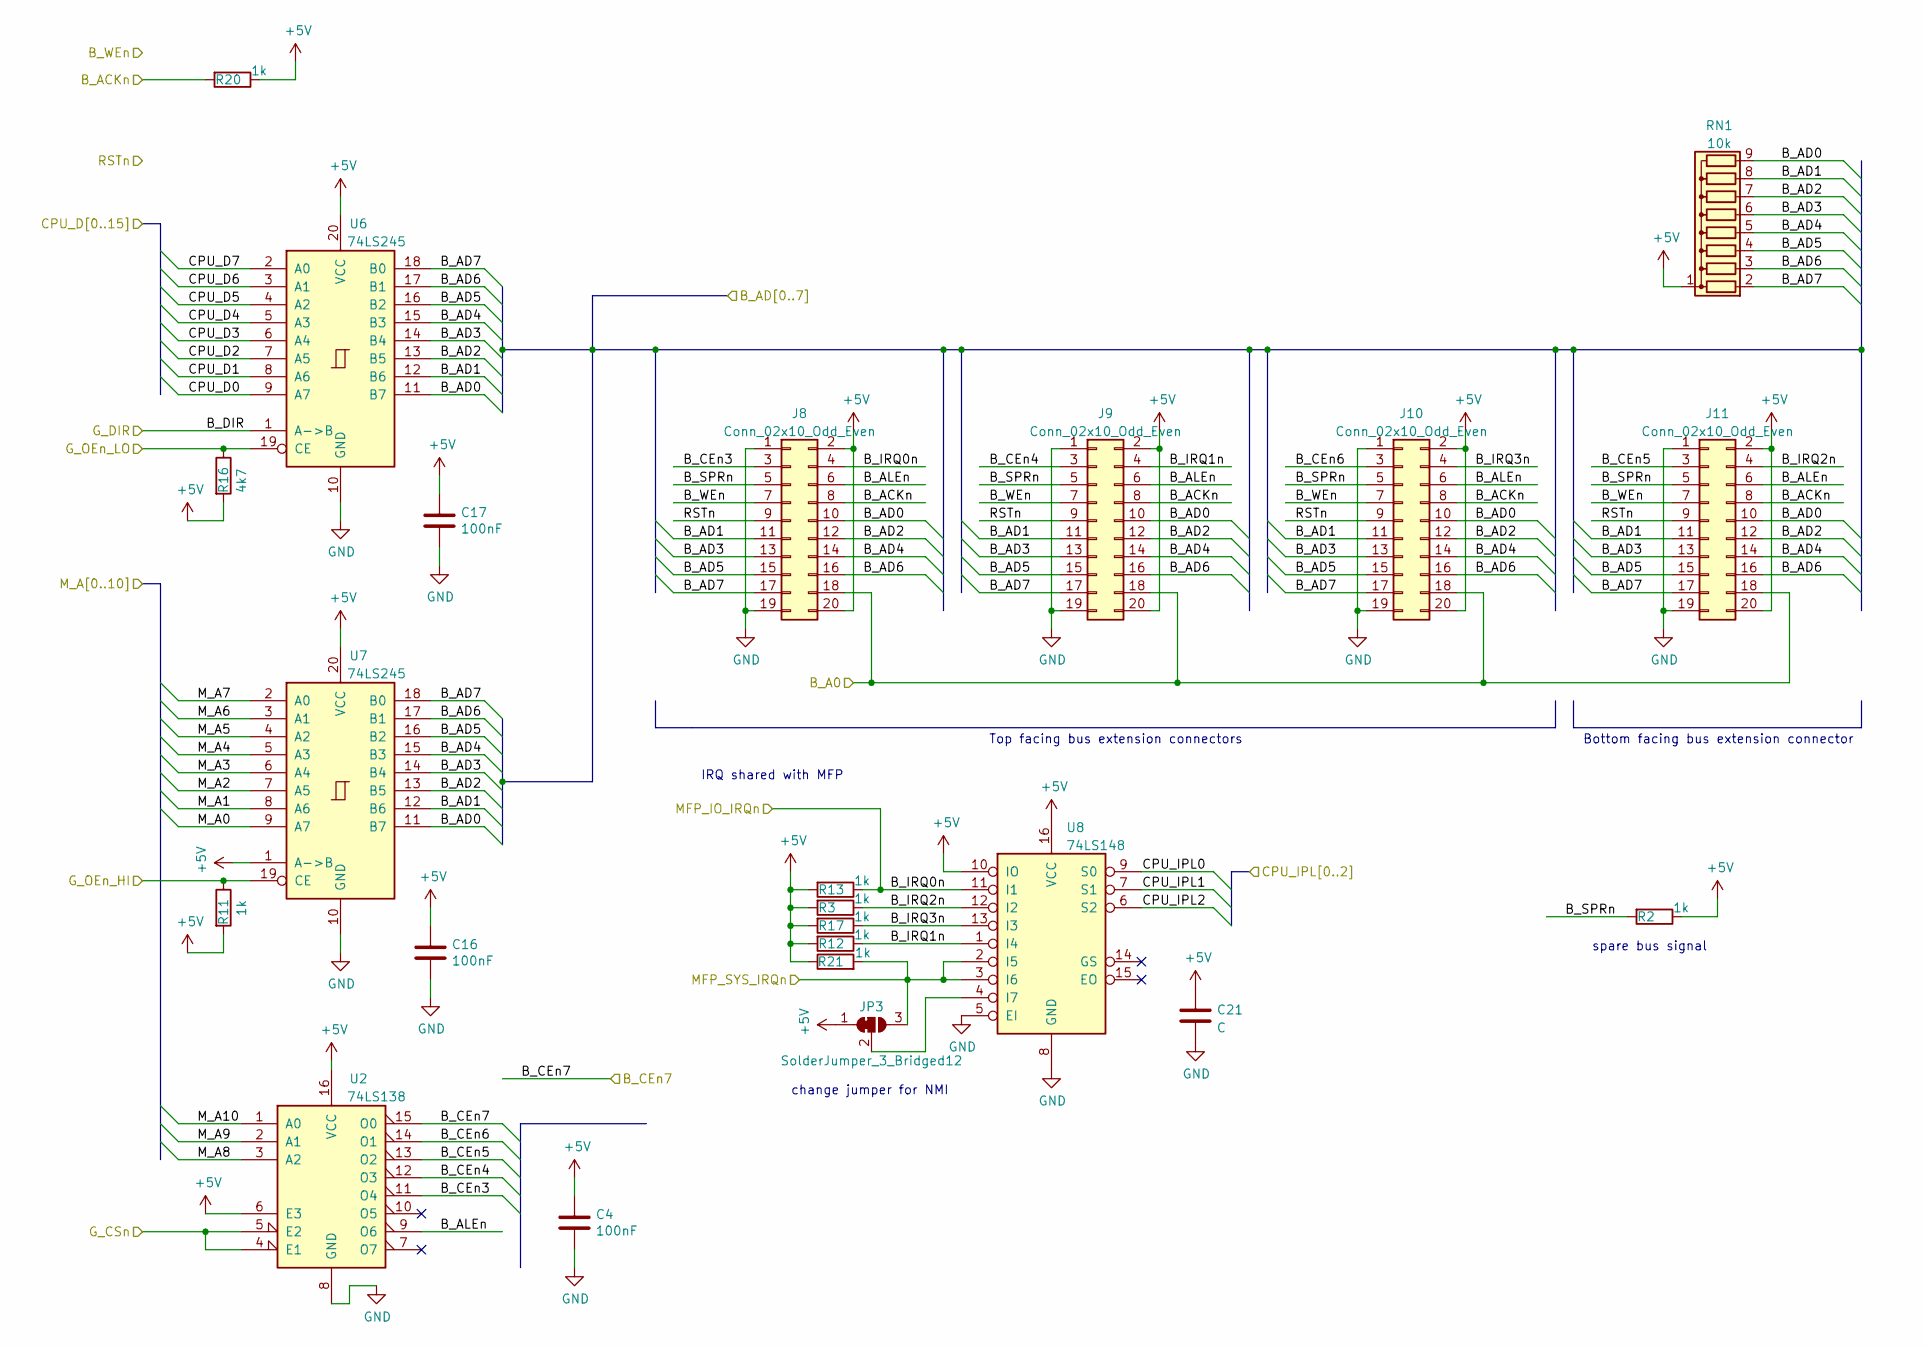
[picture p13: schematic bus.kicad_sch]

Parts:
C4, C16, C17: 100nF; C_Disc_D4.3mm_W1.9mm_P5.00mm
C21: C; C_Disc_D4.3mm_W1.9mm_P5.00mm
J8, J9, J10, J11: Conn_02x10_Odd_Even; PinSocket_2x10_P2.54mm_Vertical
JP3: SolderJumper_3_Bridged12; SolderJumper-3_P1.3mm_Bridged12_RoundedPad1.0x1.5mm_NumberL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
R2, R3, R12, R13, R17, R20, R21: 1k; R_Axial_DIN0204_L3.6mm_D1.6mm_P7.62mm_Horizontal
R11: 1k; R_Axial_DIN0204_L3.6mm_D1.6mm_P2.54mm_Vertical
R16: 4k7; R_Axial_DIN0204_L3.6mm_D1.6mm_P2.54mm_Vertical
RN1: 10k; R_Array_SIP9
U2: 74LS138; DIP-16_W7.62mm_Socket
U6, U7: 74LS245; DIP-20_W7.62mm_Socket
U8: 74LS148; DIP-16_W7.62mm_Socket

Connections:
+5V: C4.1, C16.1, C17.1, C21.1, J8.2, J8.20, J9.2, J9.20, J10.2, J10.20, J11.2, J11.20, JP3.1 (A), R2.1, R3.2, R11.2, R12.2, R13.2, R16.2, R17.2, R20.1, R21.1, RN1.1 (common), U2.6 (E3), U2.16 (VCC), U6.20 (VCC), U7.1 (A->B), U7.20 (VCC), U8.10 (IO), U8.16 (VCC); also elsewhere on the board
/CPU_D0: U6.9 (A7); also elsewhere on the board
/CPU_D1: U6.8 (A6); also elsewhere on the board
/CPU_D2: U6.7 (A5); also elsewhere on the board
/CPU_D3: U6.6 (A4); also elsewhere on the board
/CPU_D4: U6.5 (A3); also elsewhere on the board
/CPU_D5: U6.4 (A2); also elsewhere on the board
/CPU_D6: U6.3 (A1); also elsewhere on the board
/CPU_D7: U6.2 (A0); also elsewhere on the board
/CPU_IPL0: U8.9 (S0); also elsewhere on the board
/CPU_IPL1: U8.7 (S1); also elsewhere on the board
/CPU_IPL2: U8.6 (S2); also elsewhere on the board
/M_A0: U7.9 (A7); also elsewhere on the board
/M_A1: U7.8 (A6); also elsewhere on the board
/M_A2: U7.7 (A5); also elsewhere on the board
/M_A3: U7.6 (A4); also elsewhere on the board
/M_A4: U7.5 (A3); also elsewhere on the board
/M_A5: U7.4 (A2); also elsewhere on the board
/M_A6: U7.3 (A1); also elsewhere on the board
/M_A7: U7.2 (A0); also elsewhere on the board
/M_A8: U2.3 (A2); also elsewhere on the board
/M_A9: U2.2 (A1); also elsewhere on the board
/M_A10: U2.1 (A0); also elsewhere on the board
/RSTn: J8.9, J9.9, J10.9, J11.9; also elsewhere on the board
/bus/B_ACKn: J8.8, J9.8, J10.8, J11.8, R20.2; also elsewhere on the board
/bus/B_AD0: J8.10, J9.10, J10.10, J11.10, RN1.9 (R8), U6.11 (B7), U7.11 (B7); also elsewhere on the board
/bus/B_AD1: J8.11, J9.11, J10.11, J11.11, RN1.8 (R7), U6.12 (B6), U7.12 (B6); also elsewhere on the board
/bus/B_AD2: J8.12, J9.12, J10.12, J11.12, RN1.7 (R6), U6.13 (B5), U7.13 (B5); also elsewhere on the board
/bus/B_AD3: J8.13, J9.13, J10.13, J11.13, RN1.6 (R5), U6.14 (B4), U7.14 (B4); also elsewhere on the board
/bus/B_AD4: J8.14, J9.14, J10.14, J11.14, RN1.5 (R4), U6.15 (B3), U7.15 (B3); also elsewhere on the board
/bus/B_AD5: J8.15, J9.15, J10.15, J11.15, RN1.4 (R3), U6.16 (B2), U7.16 (B2); also elsewhere on the board
/bus/B_AD6: J8.16, J9.16, J10.16, J11.16, RN1.3 (R2), U6.17 (B1), U7.17 (B1); also elsewhere on the board
/bus/B_AD7: J8.17, J9.17, J10.17, J11.17, RN1.2 (R1), U6.18 (B0), U7.18 (B0); also elsewhere on the board
/bus/B_ALEn: J8.6, J9.6, J10.6, J11.6, U2.9 (O6)
/bus/B_CEn3: J8.3, U2.11 (O4)
/bus/B_CEn4: J9.3, U2.12 (O3)
/bus/B_CEn5: J11.3, U2.13 (O2)
/bus/B_CEn6: J10.3, U2.14 (O1)
/bus/B_CEn7: U2.15 (O0); also elsewhere on the board
/bus/B_DIR: U6.1 (A->B); also elsewhere on the board
/bus/B_IRQ0n: J8.4, R13.1, U8.11 (I1); also elsewhere on the board
/bus/B_IRQ1n: J9.4, R12.1, U8.1 (I4)
/bus/B_IRQ2n: J11.4, R3.1, U8.12 (I2)
/bus/B_IRQ3n: J10.4, R17.1, U8.13 (I3)
/bus/B_SPRn: J8.5, J9.5, J10.5, J11.5, R2.2
/bus/B_WEn: J8.7, J9.7, J10.7, J11.7; also elsewhere on the board
/glue/B_A0: J8.18, J9.18, J10.18, J11.18; also elsewhere on the board
/glue/G_CSn: U2.4 (E1), U2.5 (E2); also elsewhere on the board
/glue/G_OEn_HI: R11.1, U7.19 (CE); also elsewhere on the board
/glue/G_OEn_LO: R16.1, U6.19 (CE); also elsewhere on the board
/io/MFP_SYS_IRQn: JP3.3 (B), R21.2, U8.2 (I5), U8.3 (I6); also elsewhere on the board
GND: C4.2, C16.2, C17.2, C21.2, J8.1, J8.19, J9.1, J9.19, J10.1, J10.19, J11.1, J11.19, U2.8 (GND), U6.10 (GND), U7.10 (GND), U8.5 (EI), U8.8 (GND); also elsewhere on the board
unnamed: JP3.2 (C), U8.4 (I7)

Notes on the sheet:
Bottom facing bus extension connector
spare bus signal
change jumper for NMI
IRQ shared with MFP
Top facing bus extension connectors

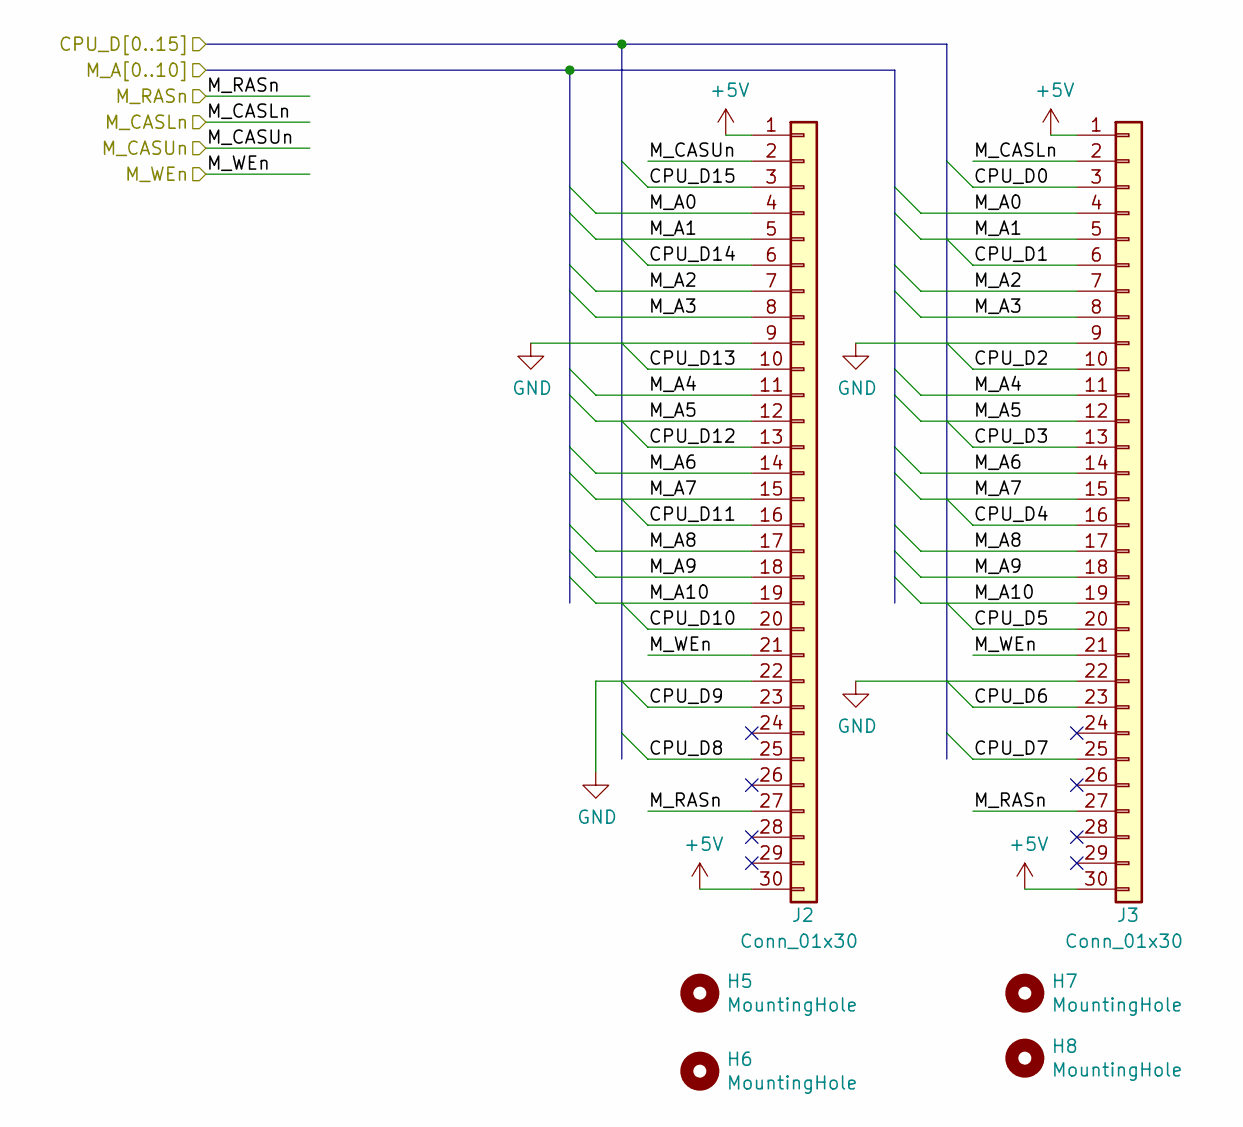
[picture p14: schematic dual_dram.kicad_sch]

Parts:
H5, H6, H7, H8: MountingHole; MountingHole_2.7mm_M2.5_DIN965_Pad
J2, J3: Conn_01x30; PinHeader_1x30_P2.54mm_Vertical

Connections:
+5V: J2.1, J2.30, J3.1, J3.30; also elsewhere on the board
/CPU_D0: J3.3; also elsewhere on the board
/CPU_D1: J3.6; also elsewhere on the board
/CPU_D2: J3.10; also elsewhere on the board
/CPU_D3: J3.13; also elsewhere on the board
/CPU_D4: J3.16; also elsewhere on the board
/CPU_D5: J3.20; also elsewhere on the board
/CPU_D6: J3.23; also elsewhere on the board
/CPU_D7: J3.25; also elsewhere on the board
/CPU_D8: J2.25; also elsewhere on the board
/CPU_D9: J2.23; also elsewhere on the board
/CPU_D10: J2.20; also elsewhere on the board
/CPU_D11: J2.16; also elsewhere on the board
/CPU_D12: J2.13; also elsewhere on the board
/CPU_D13: J2.10; also elsewhere on the board
/CPU_D14: J2.6; also elsewhere on the board
/CPU_D15: J2.3; also elsewhere on the board
/M_A0: J2.4, J3.4; also elsewhere on the board
/M_A1: J2.5, J3.5; also elsewhere on the board
/M_A2: J2.7, J3.7; also elsewhere on the board
/M_A3: J2.8, J3.8; also elsewhere on the board
/M_A4: J2.11, J3.11; also elsewhere on the board
/M_A5: J2.12, J3.12; also elsewhere on the board
/M_A6: J2.14, J3.14; also elsewhere on the board
/M_A7: J2.15, J3.15; also elsewhere on the board
/M_A8: J2.17, J3.17; also elsewhere on the board
/M_A9: J2.18, J3.18; also elsewhere on the board
/M_A10: J2.19, J3.19; also elsewhere on the board
/M_CASLn: J3.2; also elsewhere on the board
/M_CASUn: J2.2; also elsewhere on the board
/M_RASn: J2.27, J3.27; also elsewhere on the board
/M_WEn: J2.21, J3.21; also elsewhere on the board
GND: J2.9, J2.22, J3.9, J3.22; also elsewhere on the board

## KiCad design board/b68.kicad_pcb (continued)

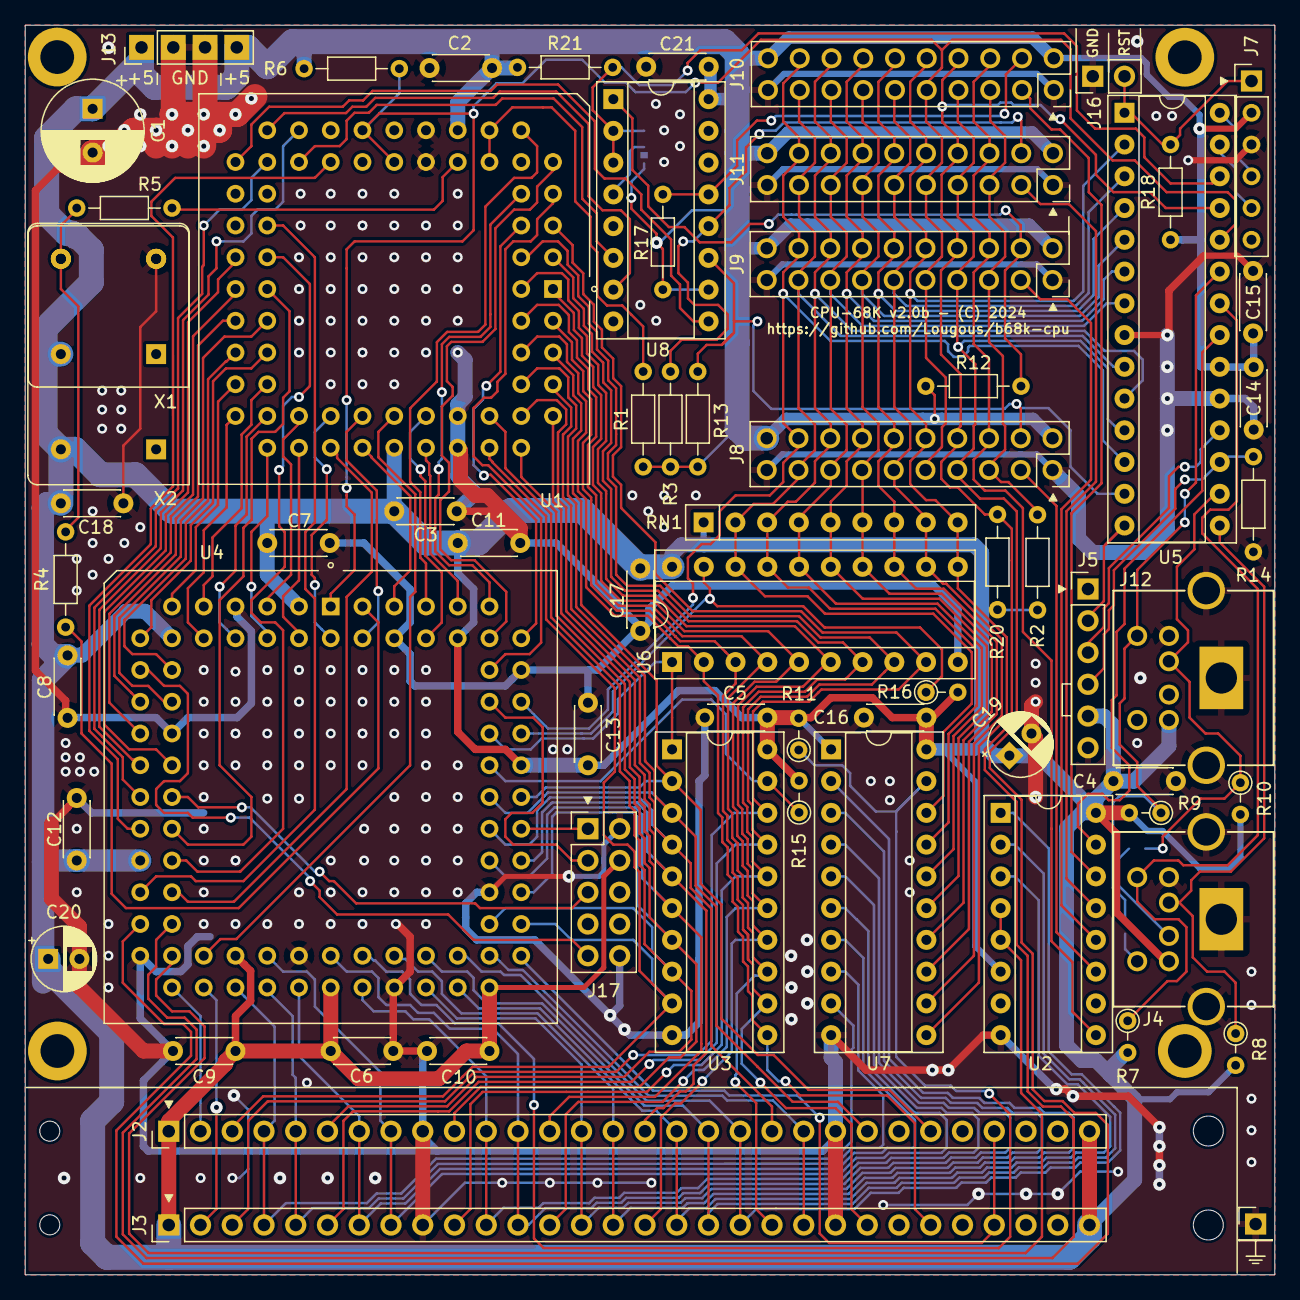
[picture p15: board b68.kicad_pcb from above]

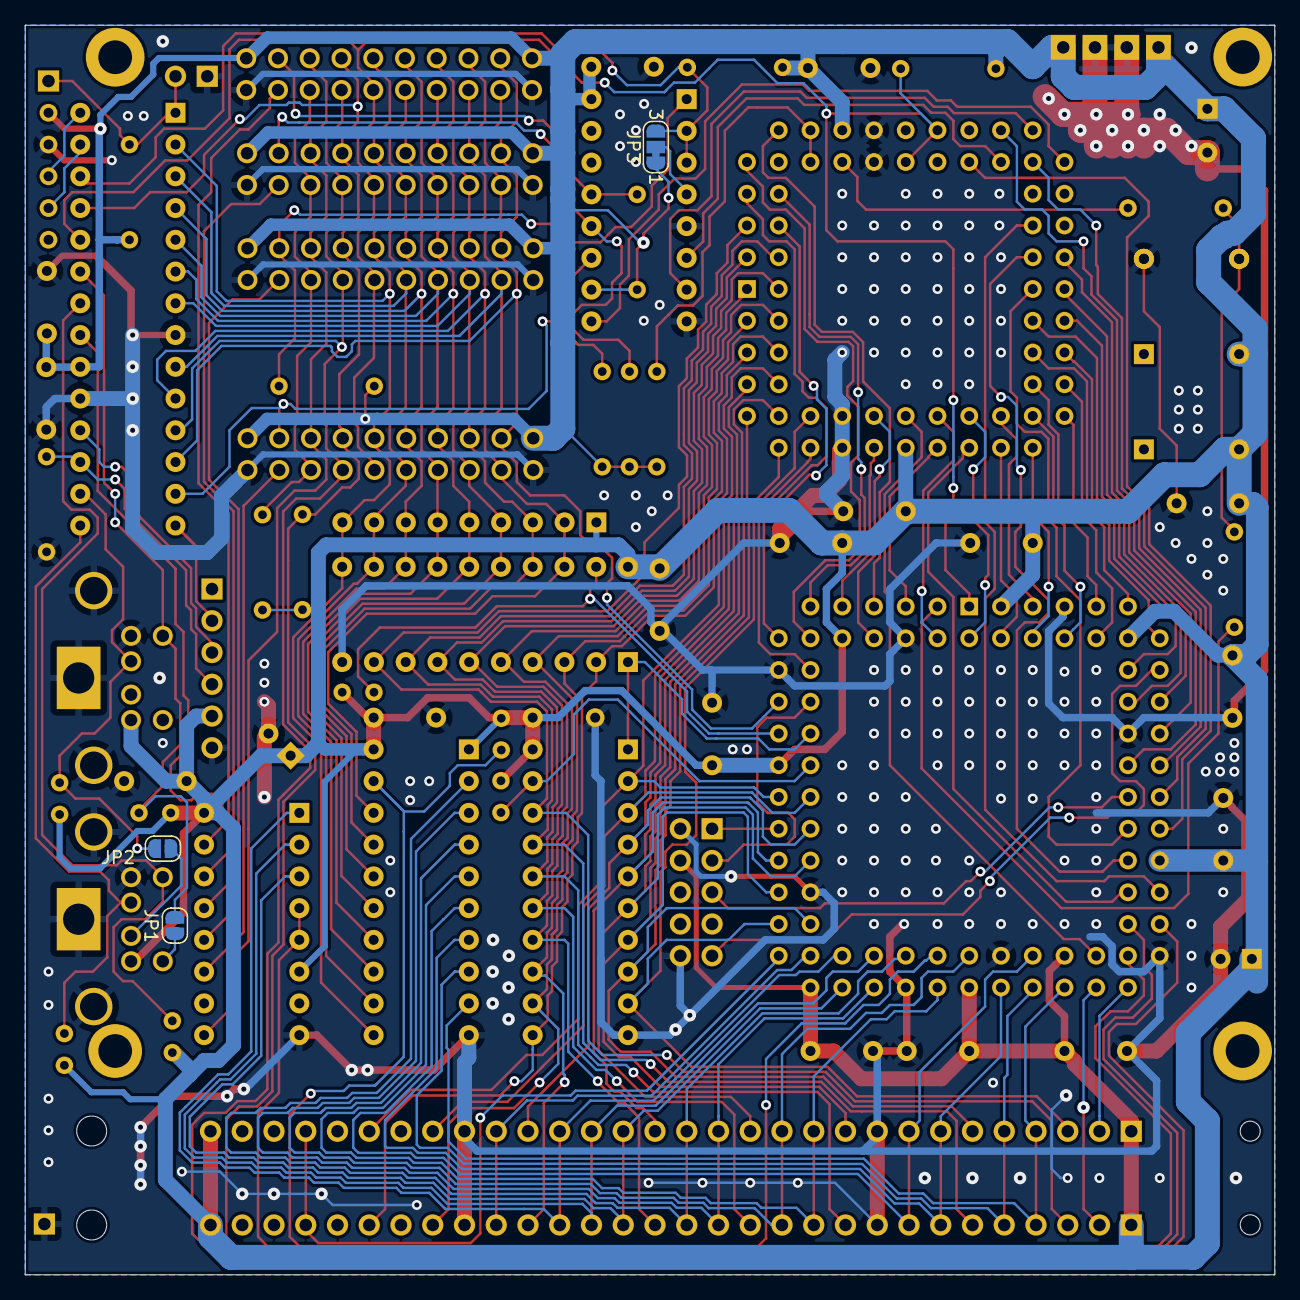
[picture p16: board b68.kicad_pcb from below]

Board: 2 copper layers, 100.0 x 100.0 mm, 77 parts (3 on the bottom side), 117 nets.

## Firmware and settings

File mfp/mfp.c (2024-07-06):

//
// firmware for b68k CPU board MFP chip
//   https://github.com/Lougous/b68k-cpu
//
// target: PIC18F27K42
// 

// PIC18F24K42 Configuration Bit Settings

// 'C' source line config statements

// CONFIG1L
#pragma config FEXTOSC = OFF    // External Oscillator Selection (HS (crystal oscillator) above 8 MHz; PFM set to high power)
#pragma config RSTOSC = HFINTOSC_64MHZ// Reset Oscillator Selection (HFINTOSC with HFFRQ = 64 MHz and CDIV = 1:1)

// CONFIG1H
#pragma config CLKOUTEN = OFF   // Clock out Enable bit (CLKOUT function is disabled)
#pragma config PR1WAY = ON      // PRLOCKED One-Way Set Enable bit (PRLOCK bit can be cleared and set only once)
#pragma config CSWEN = ON       // Clock Switch Enable bit (Writing to NOSC and NDIV is allowed)
#pragma config FCMEN = ON       // Fail-Safe Clock Monitor Enable bit (Fail-Safe Clock Monitor enabled)

// CONFIG2L
#pragma config MCLRE = EXTMCLR  // MCLR Enable bit (If LVP = 0, MCLR pin is MCLR; If LVP = 1, RE3 pin function is MCLR )
#pragma config PWRTS = PWRT_OFF // Power-up timer selection bits (PWRT is disabled)
#pragma config MVECEN = ON      // Multi-vector enable bit (Multi-vector enabled, Vector table used for interrupts)
#pragma config IVT1WAY = ON     // IVTLOCK bit One-way set enable bit (IVTLOCK bit can be cleared and set only once)
#pragma config LPBOREN = OFF    // Low Power BOR Enable bit (ULPBOR disabled)
#pragma config BOREN = SBORDIS  // Brown-out Reset Enable bits (Brown-out Reset enabled , SBOREN bit is ignored)

// CONFIG2H
#pragma config BORV = VBOR_2P45 // Brown-out Reset Voltage Selection bits (Brown-out Reset Voltage (VBOR) set to 2.45V)
#pragma config ZCD = OFF        // ZCD Disable bit (ZCD disabled. ZCD can be enabled by setting the ZCDSEN bit of ZCDCON)
#pragma config PPS1WAY = ON     // PPSLOCK bit One-Way Set Enable bit (PPSLOCK bit can be cleared and set only once; PPS registers remain locked after one clear/set cycle)
#pragma config STVREN = ON      // Stack Full/Underflow Reset Enable bit (Stack full/underflow will cause Reset)
#pragma config DEBUG = OFF      // Debugger Enable bit (Background debugger disabled)
#pragma config XINST = OFF      // Extended Instruction Set Enable bit (Extended Instruction Set and Indexed Addressing Mode disabled)

// CONFIG3L
#pragma config WDTCPS = WDTCPS_31// WDT Period selection bits (Divider ratio 1:65536; software control of WDTPS)
#pragma config WDTE = OFF       // WDT operating mode (WDT enabled regardless of sleep)

// CONFIG3H
#pragma config WDTCWS = WDTCWS_7// WDT Window Select bits (window always open (100%); software control; keyed access not required)
#pragma config WDTCCS = SC      // WDT input clock selector (Software Control)

// CONFIG4L
#pragma config BBSIZE = BBSIZE_512// Boot Block Size selection bits (Boot Block size is 512 words)
#pragma config BBEN = OFF       // Boot Block enable bit (Boot block disabled)
#pragma config SAFEN = OFF      // Storage Area Flash enable bit (SAF disabled)
#pragma config WRTAPP = OFF     // Application Block write protection bit (Application Block not write protected)

// CONFIG4H
#pragma config WRTB = OFF       // Configuration Register Write Protection bit (Configuration registers (300000-30000Bh) not write-protected)
#pragma config WRTC = OFF       // Boot Block Write Protection bit (Boot Block (000000-0007FFh) not write-protected)
#pragma config WRTD = OFF       // Data EEPROM Write Protection bit (Data EEPROM not write-protected)
#pragma config WRTSAF = OFF     // SAF Write protection bit (SAF not Write Protected)
#pragma config LVP = ON         // Low Voltage Programming Enable bit (Low voltage programming enabled. MCLR/VPP pin function is MCLR. MCLRE configuration bit is ignored)

// CONFIG5L
#pragma config CP = OFF         // PFM and Data EEPROM Code Protection bit (PFM and Data EEPROM code protection disabled)

// CONFIG5H

// #pragma config statements should precede project file includes.
// Use project enums instead of #define for ON and OFF.

#include <xc.h>

#include <stdint.h>
#include <stdio.h>
//#include <string.h>

#define _XTAL_FREQ       64000000UL  // 16 MHz (default configuration)

// debug UART
void putch(char data) {
    while( ! U1ERRIRbits.TXMTIF)          // wait until the transmitter is ready
        continue;
    U1TXB = data;                     // send one character
}

#define CEn              (PORTBbits.RB0)

#define RSTn             (PORTBbits.RB3)
#define ASSERT_RSTn      TRISBbits.TRISB3 = 0;   // output - RST# asserted
#define DEASSERT_RSTn    TRISBbits.TRISB3 = 1;   // input - RST# deasserted

#define ACKn             (PORTBbits.RB4)
#define ASSERT_ACKn      TRISBbits.TRISB4 = 0;   // output - ACK# asserted
#define DEASSERT_ACKn    TRISBbits.TRISB4 = 1;   // input - ACK# deasserted

#define IRQn             (PORTBbits.RB5)
#define ASSERT_IRQn      TRISBbits.TRISB5 = 0;   // output - IRQ# asserted
#define DEASSERT_IRQn    TRISBbits.TRISB5 = 1;   // input - IRQ# deasserted

#define WEn              (PORTCbits.RC0)

#define A0               (PORTCbits.RC1)

#define SYS_IRQn             (PORTCbits.RC2)
#define ASSERT_SYS_IRQn      TRISCbits.TRISC2 = 0;   // output - IRQ# asserted
#define DEASSERT_SYS_IRQn    TRISCbits.TRISC2 = 1;   // input - IRQ# deasserted

//#define IOEXT0           (PORTCbits.RC2)
#define IOEXT1           (PORTCbits.RC3)
#define IOEXT2_TX        (PORTCbits.RC7)
#define IOEXT3_RX        (PORTCbits.RC6)

#define BSTP             IOEXT3_RX

#define KB_DAT           (PORTCbits.RC4)
#define KB_CLK           (PORTBbits.RB1)

#define MS_DAT           (PORTCbits.RC5)
#define MS_DAT_DIR       (TRISCbits.TRISC5)

#define MS_CLK           (PORTBbits.RB2)
#define MS_CLK_DIR       (TRISBbits.TRISB2)

// boot file content
#include "../../../software/system/kernel/system-img.c"
#include "../../../software/bootstrap/bootstrap-img.c"

volatile unsigned short kbd_dat;
volatile unsigned short kbd_sin;

volatile unsigned char  ms_recv_mode;
volatile unsigned short ms_dat;
volatile unsigned short ms_sin;
volatile unsigned short ms_parity;
volatile unsigned short ms_cmd;
volatile unsigned char  ms_bcnt;

volatile unsigned char uart_rxbuf[256];
volatile unsigned char uart_rxb_w;
volatile unsigned char uart_rxb_r;

#define UART_RUDF_BIT    0x01     // receive FIFO underflow
#define UART_ROVF_BIT    0x02     // receive FIFO overflow
volatile unsigned char uart_sts;

#define IRQ_RTC_MASK   0x01
#define IRQ_KBD_MASK   0x02
#define IRQ_MS_MASK    0x04
#define IRQ_UART_MASK  0x08
volatile unsigned char irq_cfg;
volatile unsigned char irq_sts;

#define SYS_TMR_IRQ_MASK   0x01
#define SYS_SELF_IRQ_MASK  0x40
#define SYS_RESET_MASK     0x80
volatile unsigned char sys_cfg;
volatile unsigned char sys_sts;

// interrupt handler for external interrupt #1
void __interrupt (irq(INT1),high_priority) _IRQ_handler_keyboard(void)
{
    uint8_t din = KB_DAT;

    // kind of SW filtering
    // ensure clock is really low: it should always be, but sometimes not ...
	if (KB_CLK == 0) {
		// interrupt 1: keyboard
		kbd_sin = (((unsigned short)din) << 15) | (kbd_sin >> 1);

        if (!(kbd_sin & 32)) {
            if (irq_cfg & IRQ_KBD_MASK) {
                ASSERT_IRQn;
                irq_sts |= IRQ_KBD_MASK;
            }
            
			kbd_dat = kbd_sin;
			kbd_sin = 0xffff;
		}

	}
    
	// clear interrupt
	PIR5bits.INT1IF = 0;
}

// interrupt handler for external interrupt #1
void __interrupt (irq(INT2),high_priority) _IRQ_handler_mouse(void)
{
    uint8_t din = MS_DAT;
    
    // kind of SW filtering
    // ensure clock is really low: it should always be, but sometimes not ...
	if (MS_CLK == 0) {

        if (ms_recv_mode == 1) {
        	// mouse => microcontroller
        	ms_sin = (((unsigned short)din) << 15) | (ms_sin >> 1);

            if (!(ms_sin & 32)) {
                if (irq_cfg & IRQ_MS_MASK) {
                    ASSERT_IRQn;
                    irq_sts |= IRQ_MS_MASK;
                }
            
                ms_dat = ms_sin;
                ms_sin = 0xffff;
            }

        } else {
            // microcontroller => mouse
            MS_DAT_DIR = ms_sin & 1;
            ms_sin = 0x8000 | (ms_sin >> 1);

            ms_bcnt++;
            
            if (ms_bcnt == 11) {
            	// end of message
                //__delay_ms(100);
                ms_recv_mode = 1;
            }
        }
    }
    
    // clear interrupt
	PIR7bits.INT2IF = 0;
}


// interrupt handler for timer 2: mouse command send start
void __interrupt(irq(IRQ_TMR2),high_priority) _IRQ_handler_TMR2(void)
{
    // Clear the interrupt flag
    PIR4bits.TMR2IF = 0;
 
    // re-enable external interrupt as next clock pulses will be initiated by 
    // the device
	PIR7bits.INT2IF = 0;
    PIE7bits.INT2IE = 1;
    
    // drive data low - start bit
    MS_DAT_DIR = 0;  // data = output

    __delay_us(10);
    
    // release the clock
    MS_CLK_DIR = 1;  // clock = input

    // rest of emission managed with interrupt generated by clock falling edge
}

// interrupt handler for RTC
void __interrupt(irq(IRQ_TMR0),high_priority) _IRQ_handler_TMR0(void)
{
    // Clear the interrupt flag
    PIR3bits.TMR0IF = 0;
     
    // rise IRQ (or not))
    if (irq_cfg & IRQ_RTC_MASK) {
        irq_sts |= IRQ_RTC_MASK;
        ASSERT_IRQn;
    }
}

// interrupt handler for system timer
void __interrupt(irq(IRQ_TMR1),high_priority) _IRQ_handler_TMR1(void)
{
    // restart timer counter (useful for self interrupt only)
    TMR1L = 0;
    TMR1H = 0;

    // Clear the interrupt flag
    PIR4bits.TMR1IF = 0;
     
    // rise IRQ (or not))
    if (sys_cfg & SYS_TMR_IRQ_MASK) {
        sys_sts |= SYS_TMR_IRQ_MASK;
        ASSERT_SYS_IRQn;
    }
    
}

// interrupt handler for serial input
void __interrupt (irq(U1RX),high_priority) _Interrupt(void) {
    if (uart_rxb_w + 1 == uart_rxb_r) {
        uart_sts |= UART_ROVF_BIT;
    } else {
        uart_rxbuf[uart_rxb_w++] = U1RXB;
    }

    //uart_sts &= ~UART_REMPTY_BIT;
    
    if (irq_cfg & IRQ_UART_MASK) {
        irq_sts |= IRQ_UART_MASK;
        ASSERT_IRQn;
    }
}

void main(void) {
    
    ////////////////////////////////////////////////////////////////////////////
    // pins configuration
    ////////////////////////////////////////////////////////////////////////////
    // enable digital mode for all IOs
    ANSELA = 0;
    ANSELB = 0;
    ANSELC = 0;
    
    LATBbits.LATB3 = 0;     // GND = RST# asserted (when output)
    LATBbits.LATB4 = 0;     // GND = ACK# asserted (when output)
    LATBbits.LATB5 = 0;     // GND = IRQ# asserted (when output)
    LATCbits.LATC2 = 0;     // GND = SYS_IRQ# asserted (when output)

    // hold board in reset
    ASSERT_RSTn;
    DEASSERT_IRQn;
    DEASSERT_SYS_IRQn;
    DEASSERT_ACKn;
    
    ////////////////////////////////////////////////////////////////////////////
    // chip configuration
    ////////////////////////////////////////////////////////////////////////////
    OSCCON1 = 0x70;
    
    ////////////////////////////////////////////////////////////////////////////
    // debug UART
    ////////////////////////////////////////////////////////////////////////////
    uart_rxb_w = 0;
    uart_rxb_r = 0;
    uart_sts   = 0;
    
    // init uart 1
    U1CON0bits.MODE=0x0; //0x0=8bit
    U1CON0bits.RXEN=0; //disable receiver
    U1CON0bits.TXEN=0; //disable transmitter
    U1CON0bits.ABDEN=0; //disable auto baud
    U1CON0bits.BRGS=0; //baud high speed mode (4 clocks) 0=low speed (16 clocks) (recommended 0)

    //setup control register 1
    U1CON1bits.SENDB=0; //break transmission disabled
    U1CON1bits.BRKOVR=0; //break transmission disabled
    U1CON1bits.RXBIMD=0; //receive break interrupt mode 
    U1CON1bits.WUE=0; //wake up enabled bit 0=receiver operates normally
    U1CON1bits.ON=0; //serial port disabled for now

    //setup control register 2
    U1CON2bits.FLO=0x0; //no flow control
    U1CON2bits.TXPOL=0; //transmit polarity control bit 0=not inverted
    U1CON2bits.C0EN=0; //checksum mode select 
    U1CON2bits.STP=0x0; //stopbit mode control 0=1 stopbit
    U1CON2bits.RXPOL=0; //receive polarity control bit 0=not inverted 
    U1CON2bits.RUNOVF=0; //run during overflow control bit

    //setup baud rate
    U1BRGL=34;             // BRGS = 0 => BRG = (fCPU / (16 * baud)) - 1
    U1BRGH=0;

#if 0
    //set uart 1 pins to extension connector (J5)
    // TX: RC7 (pin 18)
    TRISCbits.TRISC7 = 0;   // output
    RC7PPS=0b00010011;
  
    // RX: RC6 (pin 17)
    TRISCbits.TRISC6 = 1;   // input
    U1RXPPS=0b00010110;
#else
    //set uart 1 pins to debug connector (J7)
    // TX: RB6 (pin 27)
    TRISBbits.TRISB6 = 0;   // output
    RB6PPS=0b00010011;
  
    // RX: RB7 (pin 28)
    TRISBbits.TRISB7 = 1;   // input
    U1RXPPS=0b00001111;    
#endif
    
    // enable interrupt
    PIE3bits.U1RXIE = 1;
    
    // enable
    U1CON1bits.ON=1;   //serial port enabled
    U1CON0bits.TXEN=1;
    U1CON0bits.RXEN=1;

    
    ////////////////////////////////////////////////////////////////////////////
    // keyboard GPIO + external interrupt
    ////////////////////////////////////////////////////////////////////////////
    kbd_dat = 0xffff;
	kbd_sin = 0xffff;

    INT1PPS = 0b01001;  // RB1 (pin 22)
	TRISCbits.TRISC4  = 1;  // RC4 (pin 15) is input (PS/2 data)
    
	INTCON0bits.INT1EDG = 0;  // interrupt on falling edge
//	INTCON0bits.INT1EDG = 1;  // interrupt on rising edge
	IPR5bits.INT1IP     = 1;  // high priority
	PIE5bits.INT1IE     = 1;  // interrupt enabled

    
    ////////////////////////////////////////////////////////////////////////////
    // mouse GPIO + external interrupt
    ////////////////////////////////////////////////////////////////////////////
    ms_dat = 0xffff;
	ms_sin = 0xffff;
	ms_recv_mode = 1;
    
    INT2PPS = 0b01010;   // RB2 (pin 23)
    LATBbits.LATB2 = 0;  // PS/2 clock : GND = asserted (when output)
	MS_DAT_DIR     = 1;  // RC5 (pin 16) is input (PS/2 data)
    LATBbits.LATB5 = 0;  // PS/2 data : GND = asserted (when output)
    
	INTCON0bits.INT2EDG = 0;  // interrupt on falling edge
//	INTCON0bits.INT2EDG = 1;  // interrupt on rising edge
	IPR7bits.INT2IP     = 1;  // high priority
	PIE7bits.INT2IE     = 1;  // interrupt enabled


    ////////////////////////////////////////////////////////////////////////////
    // RTC timer + interrupt
    ////////////////////////////////////////////////////////////////////////////
    irq_cfg = 0;
    irq_sts = 0;
    
    T0CON0bits.EN   = 1;  // Enable TMR0
    T0CON0bits.MD16 = 0;  // 8-bits mode
    T0CON1bits.CS   = 5;  // 500 kHz
    T0CON1bits.CKPS = 1;  // 1 => 1:2 => ~ 1kHz
    
    TMR0H = 249;
//    TMR0L = 0;
    
    IPR3bits.TMR0IP = 1;  // Make TMR0 interrupt high priority
    PIE3bits.TMR0IE = 1;  // Enable TMR0 interrupt
    
    ////////////////////////////////////////////////////////////////////////////
    // system timer + interrupt
    ////////////////////////////////////////////////////////////////////////////
    sys_cfg = 0;
    sys_sts = 0;
    
    T1CLKbits.CS   = 1;  // Fosc/4  16MHz

    T1GCON   = 0;  // no gating

    TMR1H = 0;
    TMR1L = 0;
    T1CONbits.CKPS = 0;  // 0 => 1:1
    
    // period: 64k x 62.5ns ~= 4 ms
    
    T1CONbits.ON   = 1;  // Enable TMR1
  
    IPR4bits.TMR1IP = 1;  // Make TMR1 interrupt high priority
    PIE4bits.TMR1IE = 1;  // Enable TMR1 interrupt

    ////////////////////////////////////////////////////////////////////////////
    // one shot timer for PS/2 mouse commands
    ////////////////////////////////////////////////////////////////////////////
    T2CLKbits.CS = 5;     // MFINTOSC (500 kHz)
    T2PR = 100;           // 200 us
    T2TMR = 0;
    T2HLTbits.MODE = 8;   // one shot
    IPR4bits.TMR2IP = 1;  // Make TMR2 interrupt high priority
    PIE4bits.TMR2IE = 1;  // Enable TMR2 interrupt
    
    ////////////////////////////////////////////////////////////////////////////
    // delay for PSU ramp-up
    ////////////////////////////////////////////////////////////////////////////
    __delay_ms(500);

    ////////////////////////////////////////////////////////////////////////////
    // general interrupt
    ////////////////////////////////////////////////////////////////////////////
    INTCON0bits.IPEN = 0;  // high/low priority
    INTCON0bits.GIE = 1;   // enable unmasked interrupts
     
    ////////////////////////////////////////////////////////////////////////////
    // allows some time to select bootstrap by pressing 's' on keyboard
    ////////////////////////////////////////////////////////////////////////////
    __delay_ms(500);
   
    const unsigned char *flash_base = (const unsigned char *)&system_bin[0];
    unsigned char dbg_mode = 0;
    
    if (((unsigned char)(kbd_dat >> 6)) == 0x1B) {
        // PS/2 code for 's'
        printf("[MFP] bootstrap ROM\n");
        flash_base = (const unsigned char *)&bootstrap_bin[0];
        dbg_mode = 1;
    } else if (((unsigned char)(kbd_dat >> 6)) == 0x23) {
        // PS/2 code for 'd'
        dbg_mode = 1;        
    }
    
    ////////////////////////////////////////////////////////////////////////////
    // bootstrap
    ////////////////////////////////////////////////////////////////////////////
    unsigned short flash_address = 0;

    while (flash_address < 512) {
        
    if (dbg_mode) printf("[MFP] +rst\n");
    ASSERT_RSTn;
    DEASSERT_ACKn;
    DEASSERT_IRQn;
    DEASSERT_SYS_IRQn;

    __delay_ms(300);  // at least 100 ms
    
    if (dbg_mode) printf("[MFP] -rst\n");
    DEASSERT_RSTn;
    
     // ensure reset not asserted by someone else
    while (! RSTn);

    __delay_us(1);  // must not exceed tRAS max (10 us)

    // read bootstrap option pin
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

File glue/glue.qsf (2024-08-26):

# -------------------------------------------------------------------------- #
#
# Copyright (C) 1991-2013 Altera Corporation
# Your use of Altera Corporation's design tools, logic functions 
# and other software and tools, and its AMPP partner logic 
# functions, and any output files from any of the foregoing 
# (including device programming or simulation files), and any 
# associated documentation or information are expressly subject 
# to the terms and conditions of the Altera Program License 
# Subscription Agreement, Altera MegaCore Function License 
# Agreement, or other applicable license agreement, including, 
# without limitation, that your use is for the sole purpose of 
# programming logic devices manufactured by Altera and sold by 
# Altera or its authorized distributors.  Please refer to the 
# applicable agreement for further details.
#
# -------------------------------------------------------------------------- #
#
# Quartus II 32-bit
# Version 13.0.1 Build 232 06/12/2013 Service Pack 1 SJ Web Edition
# Date created = 21:01:15  November 10, 2020
#
# -------------------------------------------------------------------------- #
#
# Notes:
#
# 1) The default values for assignments are stored in the file:
#		glue_assignment_defaults.qdf
#    If this file doesn't exist, see file:
#		assignment_defaults.qdf
#
# 2) Altera recommends that you do not modify this file. This
#    file is updated automatically by the Quartus II software
#    and any changes you make may be lost or overwritten.
#
# -------------------------------------------------------------------------- #

# global settings
set_global_assignment -name FAMILY MAX7000S
set_global_assignment -name DEVICE "EPM7128SLC84-10"
set_global_assignment -name TOP_LEVEL_ENTITY glue
set_global_assignment -name ORIGINAL_QUARTUS_VERSION "13.0 SP1"
set_global_assignment -name PROJECT_CREATION_TIME_DATE "21:01:15  NOVEMBER 10, 2020"
set_global_assignment -name LAST_QUARTUS_VERSION "13.0 SP1"
set_global_assignment -name PROJECT_OUTPUT_DIRECTORY output_files
set_global_assignment -name DEVICE_FILTER_PACKAGE PLCC
set_global_assignment -name DEVICE_FILTER_PIN_COUNT 84
set_global_assignment -name DEVICE_FILTER_SPEED_GRADE 10
set_global_assignment -name ERROR_CHECK_FREQUENCY_DIVISOR "-1"
set_global_assignment -name MAX7000_DEVICE_IO_STANDARD TTL
set_global_assignment -name OPTIMIZE_HOLD_TIMING OFF
set_global_assignment -name OPTIMIZE_MULTI_CORNER_TIMING OFF
set_global_assignment -name FITTER_EFFORT "STANDARD FIT"
set_global_assignment -name RESERVE_ALL_UNUSED_PINS_NO_OUTPUT_GND "AS INPUT TRI-STATED"
set_global_assignment -name POWER_USE_PVA OFF
set_global_assignment -name FORCE_FITTER_TO_AVOID_PERIPHERY_PLACEMENT_WARNINGS ON

# file(s)
set_global_assignment -name VHDL_FILE glue.vhd

# pinout
set_location_assignment PIN_83 -to GCLK
set_location_assignment PIN_1 -to RSTn

set_location_assignment PIN_31 -to B_ACKn
set_location_assignment PIN_30 -to B_WEn
set_location_assignment PIN_70 -to B_A0
set_location_assignment PIN_68 -to G_OEn_LO
set_location_assignment PIN_67 -to G_OEn
set_location_assignment PIN_34 -to G_CSn
set_location_assignment PIN_69 -to G_DIR
set_location_assignment PIN_46 -to G_OEn_HI

set_location_assignment PIN_22 -to CPU_FC2
set_location_assignment PIN_80 -to CPU_A[23]
set_location_assignment PIN_77 -to CPU_A[22]
set_location_assignment PIN_36 -to CPU_A[21]
set_location_assignment PIN_84 -to CPU_A[20]
set_location_assignment PIN_81 -to CPU_A[19]
set_location_assignment PIN_2 -to CPU_A[18]
set_location_assignment PIN_29 -to CPU_A[17]
set_location_assignment PIN_5 -to CPU_A[16]
set_location_assignment PIN_4 -to CPU_A[15]
set_location_assignment PIN_8 -to CPU_A[14]
set_location_assignment PIN_6 -to CPU_A[13]
set_location_assignment PIN_10 -to CPU_A[12]
set_location_assignment PIN_9 -to CPU_A[11]
set_location_assignment PIN_11 -to CPU_A[10]
set_location_assignment PIN_12 -to CPU_A[9]
set_location_assignment PIN_15 -to CPU_A[8]
set_location_assignment PIN_17 -to CPU_A[7]
set_location_assignment PIN_16 -to CPU_A[6]
set_location_assignment PIN_25 -to CPU_A[5]
set_location_assignment PIN_18 -to CPU_A[4]
set_location_assignment PIN_27 -to CPU_A[3]
set_location_assignment PIN_21 -to CPU_A[2]
set_location_assignment PIN_28 -to CPU_A[1]
set_location_assignment PIN_74 -to CPU_ASn
set_location_assignment PIN_20 -to CPU_BERRn
set_location_assignment PIN_56 -to CPU_D[15]
set_location_assignment PIN_57 -to CPU_D[14]
set_location_assignment PIN_58 -to CPU_D[13]
set_location_assignment PIN_61 -to CPU_D[12]
set_location_assignment PIN_60 -to CPU_D[11]
set_location_assignment PIN_63 -to CPU_D[10]
set_location_assignment PIN_65 -to CPU_D[9]
set_location_assignment PIN_64 -to CPU_D[8]
set_location_assignment PIN_76 -to CPU_RWn
set_location_assignment PIN_75 -to CPU_LDSn
set_location_assignment PIN_73 -to CPU_UDSn
set_location_assignment PIN_24 -to CPU_VPAn
set_location_assignment PIN_79 -to CPU_DTACKn

set_location_assignment PIN_52 -to M_A[10]
set_location_assignment PIN_50 -to M_A[9]
set_location_assignment PIN_51 -to M_A[8]
set_location_assignment PIN_48 -to M_A[7]
set_location_assignment PIN_49 -to M_A[6]
set_location_assignment PIN_44 -to M_A[5]
set_location_assignment PIN_45 -to M_A[4]
set_location_assignment PIN_40 -to M_A[3]
set_location_assignment PIN_41 -to M_A[2]
set_location_assignment PIN_39 -to M_A[1]
set_location_assignment PIN_37 -to M_A[0]
set_location_assignment PIN_35 -to M_CASLn
set_location_assignment PIN_33 -to M_CASUn
set_location_assignment PIN_54 -to M_RASn
set_location_assignment PIN_55 -to M_WEn

# generate post-layout model
set_global_assignment -name EDA_SIMULATION_TOOL "ModelSim-Altera (VHDL)"
set_global_assignment -name EDA_OUTPUT_DATA_FORMAT VHDL -section_id eda_simulation

# timing
set_instance_assignment -name CUT ON -from reg_pmu_mask[*] -to pmu_access_error
set_global_assignment -name FMAX_REQUIREMENT "20 MHz" -section_id GCLK
set_instance_assignment -name CLOCK_SETTINGS GCLK -to GCLK

set_instance_assignment -name STATE_MACHINE_PROCESSING AUTO -to s_state

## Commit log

2024-05-20 add board picture
2024-05-20 import CBA files
    [b68.kicad_pcb, b68.kicad_sch, bus.kicad_sch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]
2024-05-29 ignore .kicad_prl files (local settings)
2024-05-29 import glue CPLD files
2024-06-11 add some filters
2024-06-22 filter out MPLAB generated files
2024-06-22 fix path to 68k software binary images
    [mfp.c]
2024-08-26 use VHDL case structure to implement FSM

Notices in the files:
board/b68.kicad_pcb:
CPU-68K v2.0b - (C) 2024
